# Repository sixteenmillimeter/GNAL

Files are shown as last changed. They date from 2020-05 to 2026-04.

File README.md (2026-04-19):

# GNAL

A free and open-source processing system for 16mm and Super8 film

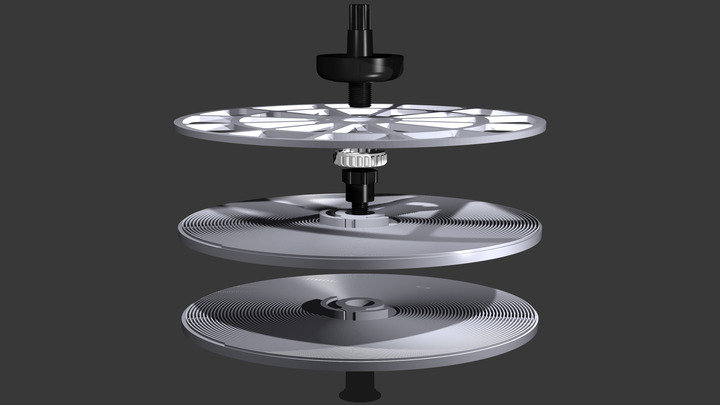
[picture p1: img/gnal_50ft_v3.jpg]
GNAL 50ft V3 all pieces


1. [What's GNAL?](#what)
2. [STL Files](#stls)
3. [Printers](#printers)
4. [Material](#material)
5. [Troubleshooting](#troubleshooting)
6. [Contact](#contact)

---

## What's GNAL? Gnal's Not A Lomo!

GNAL stands for Gnal's Not A Lomo because it isn't. 
While inspired by a certain motion picture development tank the goal of this project is to create a free, open-source, modification-friendly processing system for small format movie film with the added constraint that it be 3D printable or otherwise able to be fabricated on a small scale. 
All source code and STL files for printing will be made available in this repository.

GNAL is built using [OpenSCAD](https://www.openscad.org/): a free, open-source CAD program that uses scripts to generate objects. 
Building this project in a scripting language serves two purposes: it uses only free and open-source software to generate the GNAL processing spirals and it future-proofs the design by preserving its dimensions in human-readable text format. 
Even if OpenSCAD were to disappear tomorrow (and we sincerely hope it doesn't) it would still be possible to recreate the GNAL models in another CAD program just by reading the code and reproducing the measurements.

While the files are all free, open-source and readily available to download; actually printing them can be a challenge. 
Please read through this README for information about materials, printers and troubleshooting your prints. Check out the [development notes](docs/) if you want to modify this project. 

Happy processing!

## Other Spirals

There has been a lot of development around 3D printed processing spirals and any projects will be linked here.
If you find any, please share with the email address at the bottom of this README.

* ~~[Movie Film Spiral Developing Tank by mb_maker on Thingiverse](https://www.thingiverse.com/thing:4715086)~~
* [New 16mm developing tank on cinematography.com](https://cinematography.com/index.php?/forums/topic/83456-new-16mm-developing-tank/)

## Where's the tank?

Good question!

## Updates

Newly added to v3: reinforced spindles.
Glue or simply insert a 40mm M4 hex bolt to the top spindle and a 16mm M4 hex bolt to the bottom spindle to reinforce them and prevent breaking from overtightening or perpendicular force on the threaded areas.

----

## V3 STL Files

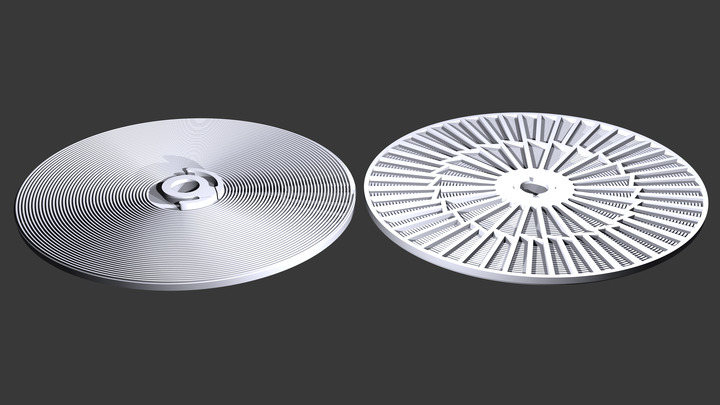
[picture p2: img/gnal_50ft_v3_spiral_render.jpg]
V3 50ft spiral top and bottom


**50ft/15m**

#### [All 50ft v3 STL files in a .zip](https://raw.githubusercontent.com/sixteenmillimeter/GNAL/main/releases/gnal_50ft_v3.zip)
#### [All 50ft v3 STL files in a .tar.gz](https://raw.githubusercontent.com/sixteenmillimeter/GNAL/main/releases/gnal_50ft_v3.tar.gz)

* [Spiral](stl/50ft_v3/gnal_50ft_spiral.stl)
* [Top](stl/50ft_v3/gnal_50ft_top.stl)
* [Top Spacer](stl/50ft_v3/gnal_50ft_spacer.stl)
* [Bottom Spiral Insert S8](stl/50ft_v3/gnal_50ft_insert_s8.stl)
* [Bottom Spiral Insert 16mm](stl/50ft_v3/gnal_50ft_insert_16.stl)
* [Bottom Spacer 16mm](stl/50ft_v3/gnal_50ft_spacer_16.stl)
* [Spindle Top](stl/50ft_v3/gnal_50ft_spindle_top.stl)
* [Spindle Top Reinforced](stl/50ft_v3.gnal_50ft_spindle_top_reinforced.stl) - Add 40mm M4 Hex Bolt
* [Spindle Bottom](stl/50ft_v3/gnal_50ft_spindle_bottom.stl)
* [Spindle Bottom Reinforced](stl/50ft_v3.gnal_50ft_spindle_bottom_reinforced.stl) - Add 16mm M4 Hex Bolt

**100ft/30m**

#### [All 100ft v3 STL files in a .zip](https://raw.githubusercontent.com/sixteenmillimeter/GNAL/main/releases/gnal_100ft_v3.zip)
#### [All 100ft v3 STL files in a .tar.gz](https://raw.githubusercontent.com/sixteenmillimeter/GNAL/main/releases/gnal_100ft_v3.tar.gz)

* [Spiral](stl/100ft_v3/gnal_100ft_spiral.stl)
* [Top](stl/100ft_v3/gnal_100ft_top.stl)
* [Top Spacer](stl/100ft_v3/gnal_100ft_spacer.stl)
* [Bottom Spiral Insert S8](stl/100ft_v3/gnal_100ft_insert_s8.stl)
* [Bottom Spiral Insert 16mm](stl/100ft_v3/gnal_100ft_insert_16.stl)
* [Bottom Spacer 16mm](stl/100ft_v3/gnal_100ft_spiral.stl)
* [Spindle Top](stl/100ft_v3/gnal_100ft_spindle_top.stl)
* [Spindle Top Reinforced](stl/50ft_v3.gnal_100ft_spindle_top_reinforced.stl) - Add 40mm M4 Hex Bolt
* [Spindle Bottom](stl/100ft_v3/gnal_100ft_spindle_bottom.stl)
* [Spindle Bottom Reinforced](stl/100ft_v3.gnal_50ft_spindle_bottom_reinforced.stl) - Add 16mm M4 Hex Bolt

## V2 STL Files

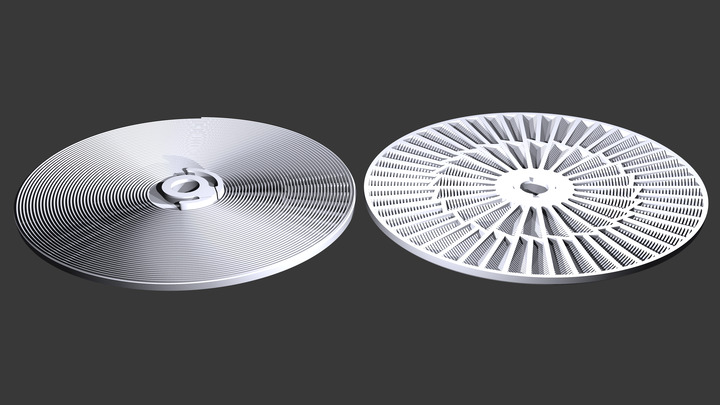
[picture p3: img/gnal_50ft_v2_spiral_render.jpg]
V2 50ft spiral top and bottom


**50ft/15m**

* [Spiral](stl/50ft_v2/gnal_50ft_spiral.stl)
* [Top](stl/50ft_v2/gnal_50ft_top.stl)
* [Top Spacer](stl/50ft_v2/gnal_50ft_spacer.stl)
* [Bottom Spiral Insert S8](stl/50ft_v2/gnal_50ft_insert_s8.stl)
* [Bottom Spiral Insert 16mm](stl/50ft_v2/gnal_50ft_insert_16.stl)
* [Bottom Spacer 16mm](stl/50ft_v2/gnal_50ft_spacer_16.stl)

**100ft/30m**

* [Spiral](stl/100ft_v2/gnal_100ft_spiral.stl)
* [Top](stl/100ft_v2/gnal_100ft_top.stl)
* [Top Spacer](stl/100ft_v2/gnal_100ft_spacer.stl)
* [Bottom Spiral Insert S8](stl/100ft_v2/gnal_100ft_spiral.stl)
* [Bottom Spiral Insert 16mm](stl/100ft_v2/gnal_100ft_insert_16.stl)
* [Bottom Spacer 16mm](stl/100ft_v2/gnal_100ft_insert_s8.stl)

## V1 STL Files

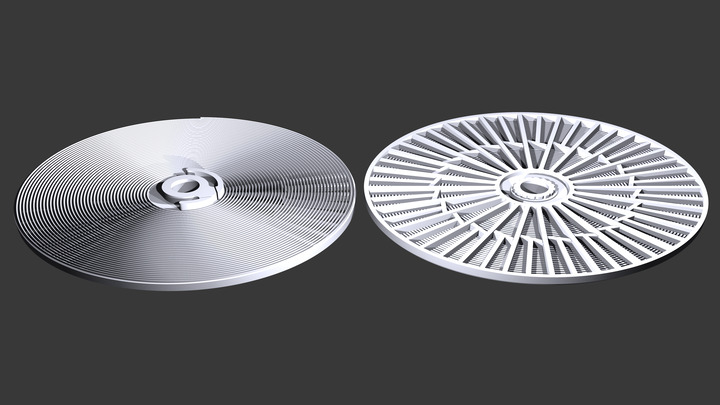
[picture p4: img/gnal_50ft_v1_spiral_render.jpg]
V1 50ft spiral top and bottom


**50ft/15m**

* [Bottom Spiral](stl/50ft_v1/gnal_50ft_spiral_bottom.stl)
* [Top Spiral](stl/50ft_v1/gnal_50ft_spiral_top.stl)
* [Top](stl/50ft_v1/gnal_50ft_top.stl)
* [Spacer](stl/50ft_v1/gnal_50ft_spacer.stl)

**100ft/30m**

* [Bottom Spiral](stl/100ft_v1/gnal_100ft_spiral_bottom.stl)
* [Top Spiral](stl/100ft_v1/gnal_100ft_spiral_top.stl)
* [Top](stl/100ft_v1/gnal_100ft_top.stl)
* [Spacer](stl/100ft_v1/gnal_100ft_spacer.stl)

-----

## Printers

The diameter of these spiral reels limit the printers that are capable of making this design. 
The 50ft/15m model is 225.71mm (8.88in) wide at the base and the 100ft/30m model is 299mm (11.77in) wide. 

**50ft/15m Capable Printers**

* [PrintrBot Metal Plus](https://www.adafruit.com/product/2302)  **Tested** **[Discontinued]**
* [LulzBot TAZ 6](https://www.lulzbot.com/store/printers/lulzbot-taz-6) Untested
* [aniwaa.com Search: Printers with print bed > 225mm x 225mm](https://www.aniwaa.com/comparison/3d-printers/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)

**100ft/30m Capable Printers**

* [Creality Ender 5 Plus](https://www.creality3d.shop/collections/3d-printer/products/creality3d-ender-5-plus-3d-printer) ***Tested***
* [aniwaa.com Search: Printers with print bed > 300mm x 300mm](https://www.aniwaa.com/comparison/3d-printers/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)

There are people printing spirals in sections on smaller printers, but that is not a *recommended* use of these files as it requires extreme precision to reconstruct the parts into a reel that will load without problems. 
Another thing to consider is the longevity of the bond made by the adhesive you choose. 
Don't let that stop you, though. A multi-part printed reel is just not a priority for *this* particular project. 
An enterprising spirit might notice the `gnal_50ft_spiral_quarter()` and `gnal_100ft_spiral_quarter()` modules in the V3 OpenSCAD scripts and begin to wonder what is possible.

-----

## Material

[PETG](https://en.wikipedia.org/wiki/Polyethylene_terephthalate#Copolymers) is currently the recommended plastic for printing the GNAL. 
Since this is a piece of darkroom processing equipment its exposure to water and photochemistry is inevitable and should be considered primarily. 
PETG (Polyethylene terephthalate glycol) is PET--which is a plastic that's typically encountered in plastic bottles and food containers--in a copolymer with glycol. 

Various manufacturers have published [safety data sheets](http://www.ilpi.com/msds/) for PETG filament. 
The only warning about reactivity I have discovered states that a condition to avoid is "strong oxidizing agents" which may include reversal bleaches that are comprised of strong acids. 
This is not a scientific evaluation and may stand to be corrected.

[ABS](https://en.wikipedia.org/wiki/Acrylonitrile_butadiene_styrene) is a viable option but has a greater tendency to warp on larger prints without proper temperature control around the print bed. 
Since this model needs to be perfectly flat across the bottom of the reel, this is not ideal and will make for a challenging print. 
ABS is a plastic commonly used in injection molding and is also generally non-reactive with photochemistry.

[PLA](https://en.wikipedia.org/wiki/Polylactic_acid) is not recommended but this doesn't mean you can't get an acceptable result with it. 
The lack of endorsement comes from mostly anecdotal experience witnessing the wear and tear caused by exposure to water on PLA prints. 
Biodegradable and porous, PLA will wear down in the weakest parts first and on this model that would be the spiral. 
If you do not need your processing equipment to last a long time, you may find it acceptable. 
PLA stands for polylactic acid and is likely the most reactive material to use with photochemistry where it is vital to maintain pH for consistent results.

-----

## Troubleshooting

Many, many issues were encountered during the development of this tool. 
Prints came out warped, failed midway during multi-day prints and had other mysterious ailments. 
I am by no means an expert but have built up months of experience trying to print these models on a variety of machines.

#### Warping

Fused filament fabrication relies on the behavior of plastics at high heat to create a physical object. 
If your prints are warping, there are a few things to look at:

1. Material
2. Temperature
3. Slicer settings

The first thing to consider when your prints are coming out warped off the print bed is whether or not your **material** is appropriate for this model. 
Check the [material](#material) section of this README for more information, but theres a chance if you are using PLA or ABS that large flat prints of this size are warping due to limitations with the material you are using. PETG has proven to warp far less in my own anecdotal experience and is the recommended material for this project.

The thermal properties of the material you're printing with are what causes warping, so check if your printer is being set to the recommended **temperatures** on both the bed and extruder for the material and printer you are using. 
Warping occurs consistently when a section of a part cools too quickly and contracts while the rest of it is still being printed. 
Mitigate this by using an enclosure on your open-frame printer or by printing in a space with low air movement but still with appropriate ventilation for the material you use.

The **slicer** you use and the **settings** in its configuration will make a lot of difference in how your print comes out. 
During the development of this project [Cura](https://ultimaker.com/software/ultimaker-cura) is the slicer used most for test prints, however you might find that different software works best with your machine. 
The settings are important to test before you commit to a complete print of the spiral part. 

Here is an example of the important settings used during development while printing with PETG.

|Setting|Value|
|---|---|
|Extruder Temperature|240<sup>o</sup> C|
|Bed Temperature|80<sup>o</sup> C|
|Generate Supports|Yes|
|Infill|20%|
|Print Speed|40 mm/s|

This is a fraction of the overall settings that Cura has, but they note some of the key features that were changed from the default profile for PETG and my printer.

-----

To read more about developing and modifying the GNAL, check out the [development notes](docs/).

-----

Had issues or success printing this? Interested in getting in contact?

# [Email me](mailto:gnal@sixteenmillimeter.com)

-----

## License

MIT License

Copyright (c) 2020 Matt McWilliams

Permission is hereby granted, free of charge, to any person obtaining a copy of this hardware, software, and associated documentation files (the "Product"), to deal in the Product without restriction, including without limitation the rights to use, copy, modify, merge, publish, distribute, sublicense, and/or sell copies of the Product, and to permit persons to whom the Product is furnished to do so, subject to the following conditions:

The above copyright notice and this permission notice shall be included in all copies or substantial portions of the Product.

THE PRODUCT IS PROVIDED "AS IS", WITHOUT WARRANTY OF ANY KIND, EXPRESS OR IMPLIED, INCLUDING BUT NOT LIMITED TO THE WARRANTIES OF MERCHANTABILITY, FITNESS FOR A PARTICULAR PURPOSE AND NONINFRINGEMENT. IN NO EVENT SHALL THE AUTHORS OR COPYRIGHT HOLDERS BE LIABLE FOR ANY CLAIM, DAMAGES OR OTHER LIABILITY, WHETHER IN AN ACTION OF CONTRACT, TORT OR OTHERWISE, ARISING FROM, OUT OF OR IN CONNECTION WITH THE PRODUCT OR THE USE OR OTHER DEALINGS IN THE PRODUCT.

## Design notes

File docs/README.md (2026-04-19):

# Development Notes

1. [Dependencies](#dependencies)
2. [Build Scripts](#scripts)
3. [Version Notes - V1](#v1)
4. [Version Notes - V2](#v2)
5. [Version Notes - V3](#v3)
6. [Benchmarks](#benchmarks)

This project can be edited with only [OpenSCAD](https://www.openscad.org/downloads.html) and the source files in the `scad/*_v1`, `scad/*_v2` or `scad/*_v3` directories which make reference to files from `scad/libraries`. 
If you wish to run the development scripts you should install the following dependencies.

With just OpenSCAD, you can use scripts such as `scad/50ft_v3/gnal_50ft.scad` and export the different modules in [OFF](https://en.wikipedia.org/wiki/OFF_(file_format)), [AMF](https://en.wikipedia.org/wiki/Additive_manufacturing_file_format), [3MF](https://en.wikipedia.org/wiki/3D_Manufacturing_Format), [DXF](https://en.wikipedia.org/wiki/AutoCAD_DXF) or SVG (drawing) format. 
The CSG models can be [imported](https://wiki.freecadweb.org/OpenSCAD_CSG) into [FreeCAD](https://www.freecadweb.org/) and DXF models should be readable by AutoCAD and [QCAD](https://www.qcad.org/en/).

-----

### Dependencies

* [Bash](https://www.gnu.org/software/bash/) - Available by default on Mac and Linux
* [OpenSCAD](https://www.openscad.org/downloads.html) + [cli](https://en.wikibooks.org/wiki/OpenSCAD_User_Manual/Using_OpenSCAD_in_a_command_line_environment) ([Mac](https://en.wikibooks.org/wiki/OpenSCAD_User_Manual/Using_OpenSCAD_in_a_command_line_environment#MacOS_notes)) ([Windows](https://en.wikibooks.org/wiki/OpenSCAD_User_Manual/Using_OpenSCAD_in_a_command_line_environment#Windows_notes))
* [ADMesh](https://github.com/admesh/admesh)
* (optional) [POV-Ray](http://www.povray.org/download/)

### Build Scripts

Running any of the build scripts scripts--`scripts/v1.sh`, `scripts/v2.sh` or `scripts/v3.sh`--will start an OpenSCAD build process of all components and will log stats about the resulting files and render times to `notes/v1.csv`,  `notes/v2.csv` or `notes/v3.csv`.

Keep in mind that V1 and V2 compile times are extremely long and all scripts will use an entire CPU core at 100% utilization while rendering. 
It's best to run these scripts in the background on a powerful machine or better yet, not at all. See the `stl` folder for pre-compiled STL files for 3D printing or the [releases page](https://github.com/sixteenmillimeter/GNAL/releases) for .zip and .tar.gz archives of all versions.

These scripts will render STL files, PNG images of the files and capture metadata about the render process while doing so.

-----

## Version Notes

### V1

Intended to be mostly compatible with existing processing spirals with some caveats. 
A spacer that is typically threaded has been replaced by a friction fit part so they are not interchangeable. 
This version is designed to fit in existing tanks and use the same spindle screws.

In the process of building this first version several approaches were evaluated to generate the spiral shape. 
The first is what's best described as a brute force approach laying out an excessive amount of rectangular facets and unioning them together in such a way that the result would be a single continuous spiral. 
This took hours to days to render depending on the machine used.

Besides the exhausting render times this approach bugged me for one reason: all facets of the spiral were the same size, meaning that the small diameter inner parts of the spiral were packing in millions of unnecessary polygons to allow for the large diameter parts of the spiral to be smooth. 
This didn't sit well with me. 
How many CPU hours are being burned by adding detail to a place that doesn't matter? 
Answer: a lot.

Finally, an external library called [`path_extrude.scad`](https://github.com/gringer/bioinfscripts/blob/master/path_extrude.scad) by [@gringer](https://github.com/gringer) was brought in to handle the complicated spiral extrusion step. 
A simple function that plots a spiral in Cartesian coordinates is used to draw the path and a 2D triangle is extruded along it by the library. 
This allowed for the path to be drawn at a consistent "resolution" throughout the entire spiral, so the facets of the outermost and innermost parts were the same or extremely similar.

Here is that function reduced to a single line in order to generate an array of coordinates.

```
spiralPath = [ for(t = [0 : $fn + 1]) [((d / 2) + (t * increment)) * cos(t * angle_i), ((d / 2) + (t * increment)) * sin(t * angle_i), 0] ];
```

The experimentation in this version predate this particular git repo and so will not be found in the git history, but you can find the vestigial functions in the `spiral` directory used for benchmarking different approaches.

#### Beware

This version of the spiral must be printed with supports. 
The spirals themselves are suspended over voids and this particular feature is addressed in the later versions. 

#### Rendering

Rendered using OpenSCAD version 2019.05 on a 2.2 GHz Core i7 (I7-4770HQ) chip running macOS 10.14.

| Model | Size (bytes) | Facets | Volume (mm<sup>3</sup>) | Render Time (sec) |
|---|---|---|---|---|
|gnal_50ft_spacer.stl|991452|5736|2888.155029|68|
|gnal_50ft_top.stl|2132181|12624|57936.746094|233|
| **gnal_50ft_spiral_top.stl** |36509561|214404|120299.773438| **12249** |
| **gnal_50ft_spiral_bottom.stl** |36606204|214970|121519.937500| **13698** |
|gnal_100ft_spacer.stl|991452|5736|2888.149658|74|
|gnal_100ft_top.stl|3302563|19552|102590.546875|477|
|gnal_100ft_spiral_top.stl|92423369|542836|223602.078125|89137|
|gnal_100ft_spiral_bottom.stl|N/A|N/A|N/A|N/A|

-----

### V2

This version aims to improve printability over the V1 model and reducing render time of the spiral. 
The biggest change to the physical structure of the design is the removal of overhangs from beneath the spiral film guide.

When printing a model with [FFF printing](https://en.wikipedia.org/wiki/Fused_filament_fabrication), any piece that overhangs empty space (usually) needs to be supported by a temporary removable structure beneath it otherwise you risk the piece drooping. 
In the case of V1 model, the spiral was completely suspended by the spokes of the reel with large gaps of empty space. 
This means there were 90 degree overhangs under the most critical part of this model; the grooves for holding the film in position. 
Printing and removing support structures from beneath the fragile spiral made post-production dangerous for the piece and time consuming.

The solution to this was to extend the spiral to the bottom of the reel and remove triangular sections from them to allow for a lighter print and better chemistry movement. 
Most printers should be able to print these structures without any support material or any resulting deformations in the model.

One other change in this version is that it reduces the spiral models to a single one to be duplicated, rather than two distinct top and a bottom pieces that differ in only minor ways. 
This decision was motivated by an interest in making this design better (cheaper) for injection molding.

A secondary benefit of reducing the spiral to a single model was to immediately cut render times for the entire project nearly in half before any other optimizations were made. 
The first meaningful code optimization toward this goal was provided by a helpful comment made on a long-forgotten design shared on a 3D printing forum. 

[@sousvide59](https://www.thingiverse.com/sousvide59/designs) (Les Smith) writes 

> It may be more efficient to approximate the spiral as a series of arc segments, like this <[Github gist](https://gist.github.com/sixteenmillimeter/839c16d39d26d04154f52b3f3ee6ee78)>.

Les was right. 
This reduced the several hours render time to 1-2 hours, which worked for this version. Ideally this will be improved further in future versions. 
Beyond some explorations into OpenSCAD hacks (rendering each complete rotation of the spiral and stitching all resulting STLs) the next version will incorporate other languages and platforms to find the fastest render time for a GNAL spiral. 
All previous approaches are being compiled into a suite of tests to benchmark render times.

#### Rendering

Rendered using OpenSCAD version 2020.01.17 on a 3.2 GHz Core i5 (I5-4460) chip running Ubuntu 18.04.

| Model | Size (bytes) | Facets | Volume (mm<sup>3</sup>) | Render Time (sec) |
|---|---|---|---|---|
|gnal_50ft_spacer.stl|991452|5736|2888.150879|22|
|gnal_50ft_top.stl|2132181|12624|57937.210938|73|
| **gnal_50ft_spiral.stl** |34628449|193450|178181.250000| **2341** |
|gnal_50ft_insert_s8.stl|5228272|27230|3493.560303|97|
|gnal_50ft_insert_16.stl|7922994|41426|4664.952637|155|
|gnal_50ft_spacer_16.stl|561267|3272|4015.912109|19|
|gnal_100ft_spacer.stl|991452|5736|2888.152100|23|
|gnal_100ft_top.stl|3302563|19552|102590.812500|118|
| **gnal_100ft_spiral.stl** |59279238|330000|345431.531250| **4542** |
|gnal_100ft_insert_s8.stl|5228272|27230|3493.559326|99|
|gnal_100ft_insert_16.stl|7922994|41426|4664.937500|160|
|gnal_100ft_spacer_16.stl|535264|3112|3964.118164|17|

-----

### V3

The goals of V3 are to **greatly** optimize the spiral generation code for speed and to restore the feature of the V1 spiral which maintains a consistent size of individual facets throughout the spiral even as the diameter changes. 
This will be considered a stable release candidate for publishing the project.

Since the benchmarking process ([see below](#benchmarks)) was developed between V2 and V3, render times are optimized in this iteration of the project. 
The success of the [`spiral_3.scad`](../scad/spiral/spiral_3.scad) approach stood out from the rest as fastest, so it was reworked into what exists in V3.

The spiral itself is plotted in 2D with a relatively simple formula that is expressed in this OpenSCAD script through a number of in-line helper functions. 
It draws the position of various points along the spiral path and then uses the `path_extrude.scad` library to extrude a shape along those coordinates. 
This proves to be fast and efficient while not sacrificing any detail in the geometry.

Prior to release a serious flaw was found while printing the V3 design. 
The attempt to remove the need for supports in V2, actually printing the spiral was creating curious side effects during fabrication. 
Not having material in the voids below the spiral, it seems, allowed air to cool the part and would consistently cause prints to fail when it reached the actual spiral at the top of the reel. 
Since this is the most important element of the reel, the triangles have been removed and the design is more similar to V1. 
Testing continues on this version.

In a compromise to make the process of removing the support material less dangerous to the detail on the top, the spiral itself extends lower than V1 into the space between the spokes of the reel. 
The spiral is also made thicker and is a multiple of my nozzle diameter (0.4mm). 
This uses slightly more material but is less fragile than V1 and test prints proved that the supports were less difficult to remove than in the earliest model.

This version will also contain a 4x reel stacking feature so that all models can be stacked with 4 spiral reels and a top piece. 
That will give 200ft capacity to the 50ft model and 400ft capacity to the 100ft model. 
A stretch goal for this version is to make a 35mm spacer and spindle set so that movie film in the format can be processed in 100ft lengths.

#### Beware

This version *also* requires the use of support material while printing.

#### Rendering

Rendered using OpenSCAD version 2020.08.18 on a 2.2 GHz Core i7 (I7-4770HQ) chip running macOS 10.14.

| Model | Size (bytes) | Facets | Volume (mm<sup>3</sup>) | Render Time (sec) |
|---|---|---|---|---|
|gnal_50ft_spindle_bottom.stl|3760384|75206|4134.077637|1291|
|gnal_50ft_spindle_top.stl|6915384|138306|22229.814453|1128|
|gnal_50ft_spacer.stl|286884|5736|2888.150635|62|
|gnal_50ft_top.stl|1104884|22096|57933.800781|585|
| **gnal_50ft_spiral.stl** |9500384|190006|171712.140625| **1111** |
|gnal_50ft_insert_s8.stl|1361584|27230|3493.544922|276|
|gnal_50ft_insert_16.stl|2071384|41426|4665.019531|439|
|gnal_50ft_spacer_16.stl|602084|12040|4019.470703|281|
|gnal_100ft_spindle_bottom.stl|3760384|75206|4134.064941|1275|
|gnal_100ft_spindle_top.stl|6979184|139582|22229.773438|1139|
|gnal_100ft_spacer.stl|286884|5736|2888.143555|63|
|gnal_100ft_top.stl|1620084|32400|102557.437500|998|
| **gnal_100ft_spiral.stl** |18364384|367286|326573.812500| **3746** |
|gnal_100ft_insert_s8.stl|1361584|27230|3493.548340|272|
|gnal_100ft_insert_16.stl|2071384|41426|4664.790527|450|
|gnal_100ft_spacer_16.stl|755684|15112|4019.479248|368|

## Benchmarks

In the process of publishing this repository I started questioning claims I was making in this README. 
Throughout the development of this processing reel I've been plagued by long render times. 
As a sanity check, I went through my personal development history on this project and produced 6 distinct spiral generation scripts that I ran through a series of tests to benchmark the render performance, total volume generated and number of facets produced. 
Render time was the primary metric that concerned me, but I considered the others important in comparing these different approaches. 

This work led to the creation of the approach in `spiral_7.scad` and was ultimately used in V3.

An example of a single test pulled from the `notes/benchmark.csv` results. 
These example results are rendered using OpenSCAD 2020.05.23 on a 2.3 GHz Xeon Gold 6140 chip running Ubuntu 18.04.

|Spiral Test|Diameter (mm)|Rotations| [$fn](https://en.wikibooks.org/wiki/OpenSCAD_User_Manual/Other_Language_Features#$fa,_$fs_and_$fn) |Size (bytes)|Facets|Volume (mm<sup>3</sup>)|Time (sec)|
|---|---|---|---|---|---|---|---|
|[spiral_1.scad](../scad/spiral/spiral_1.scad)|47|10|100|7409653|41064|5391.819336|209|
|[spiral_2.scad](../scad/spiral/spiral_2.scad)|47|10|100|15349620|86646|3639.441162|855|
|[spiral_3.scad](../scad/spiral/spiral_3.scad)|47|10|100|1336635|8004|3589.485596|0|
|[spiral_4.scad](../scad/spiral/spiral_4.scad)|47|10|100|1607691|9624|3830.134521|23|
|[spiral_5.scad](../scad/spiral/spiral_5.scad)|47|10|100|4711486|28188|3602.101562|8|
|[spiral_6.scad](../scad/spiral/spiral_6.scad)|47|10|100|4265376|25396|14337.455078|120|
|[spiral_7.scad](../scad/spiral/spiral_7.scad)|47|10|100|990006|5924|3581.499756|0|

As you can see, the different approaches lead to wildly different render times for the same test. 
If you look at the complete results you will see many tests did not even finish due to exhausting memory on the machine or the process being killed by the cloud host (using too much CPU for too long, most likely). 
In the case of `spiral_3.scad` and `spiral_7.scad` measuring "0" seconds, this just means that the process finished rendering in less than 1 second.

In the `scad/spiral` directory you will find each individual script in a `scad/spiral/spiral_#.scad` file. 
The `scripts/benchmark.sh` script will render spirals at various resolutions and rotation counts and record the results in `notes/benchmark.csv`.

Insights gleaned from these benchmarks was incorporated into the latest versions of design. 
Consider this comparison of just the 50ft spirals (top spiral from V1).

| # | Model | Size (bytes) | Facets | Volume (mm<sup>3</sup>) | Render Time (sec) |
|---|---|---|---|---|---|
| V1 | gnal_50ft_spiral_top.stl |36509561 | 214404 | 120299.773438 | 12249 |
| V2 | gnal_50ft_spiral.stl |34628449 | 193450 | 178181.250000 |  2341 |
| V3 | gnal_50ft_spiral.stl | 9500384 | 190006 | 171712.140625 |  1111 |

Render times have gone down dramatically between V1 and V2.
Times halved again between V2 and V3.
The volume has stayed consistent with major changes in geometry (between V1 and V2).
The file size of the V3 spiral has reduced to about 30% of the V1 and V2 spirals and the facet count remains roughly the same throughout (which was a surprise).

Faster render times mean more iteration and less time between tests.
The next part of the process to examine is slicing which has primarily been done with Cura, but other engines will be looked at for their speed, efficiency and print quality.

## V3 Updates

### Reinforced Spindles

The first in a list of intended updates to the V3 model is reinforcing the spindles.
This is acheived by adding voids for M4 bolts in the spindles with the intention of preventing them from snapping due to overtightening or perpendicular force on the threaded parts.
The bolts should be friction fit or added with a small amount of glue to adhere them inside the spindles.

* 1x 40mm M4 Hex Bolt *(Accepts 30-50mm bolts if needed)*
* 1x 16mm M4 Hex Bolt

### Manifold Backend

Another upgrade in the build script is the use of the [Manifold](https://manifoldcad.org/docs/html/) backend.
This drops the CPU render time dramatically, even after the spiral modifications in V3.

OpenSCAD has improved performance in the core backend since starting this project, but rendering using `--backend=manifold` drops even the most complex solid geometry calculations to times needed for fast design iterations.

### Canonical Renders

The next improvement was to introduce [c14n_stl.py](https://github.com/nophead/NopSCADlib/blob/master/scripts/c14n_stl.py) from [NopSCADlib](https://github.com/nophead/NopSCADlib) to sort compiled STLs consistently between renders.
Doing this *should* mean that different machines will produce identical STLs before they're converted to binary and prevent excessive diffs when small changes are made.
Previously this was left out to reduce the Python dependency but it is common enough as a default on many systems to mean that adding a library-free Python script is not a concern.

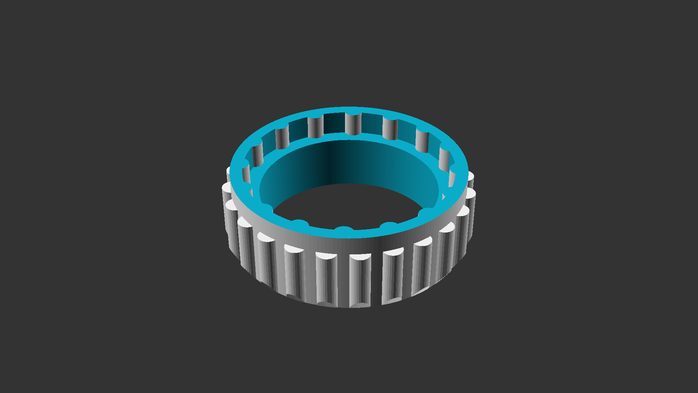
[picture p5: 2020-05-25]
img/gnal_50ft_v3_spacer.png

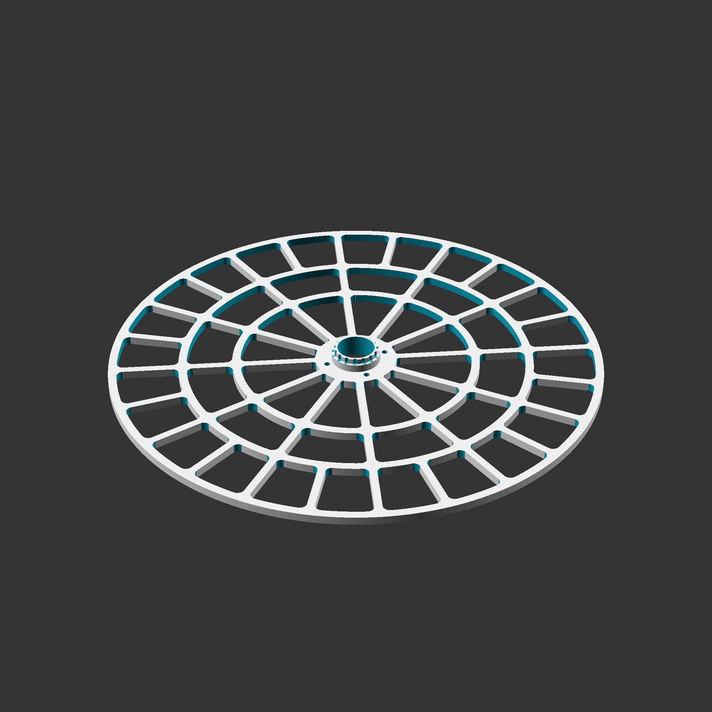
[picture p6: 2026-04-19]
img/gnal_100ft_v3_top.png

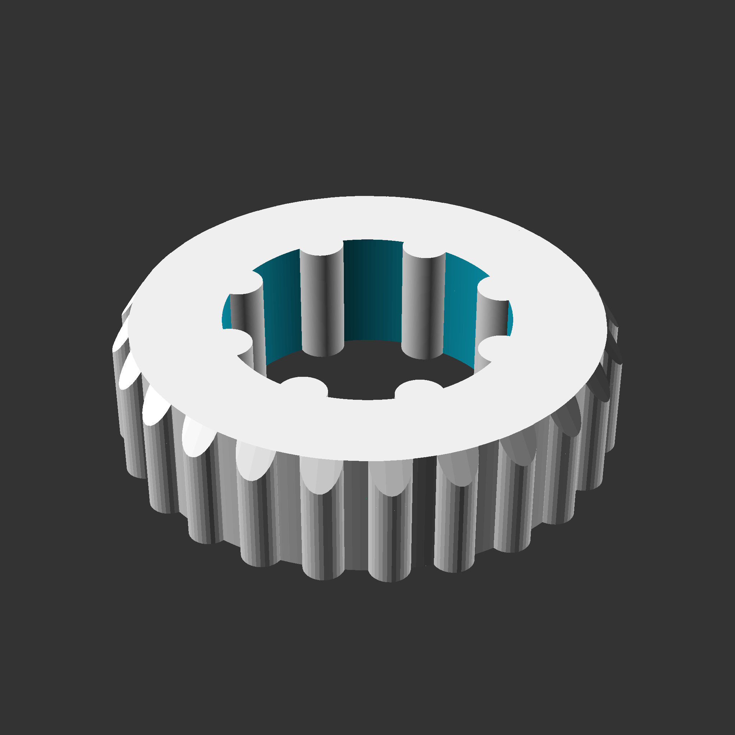
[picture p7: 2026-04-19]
img/gnal_50ft_v3_spacer_16.png

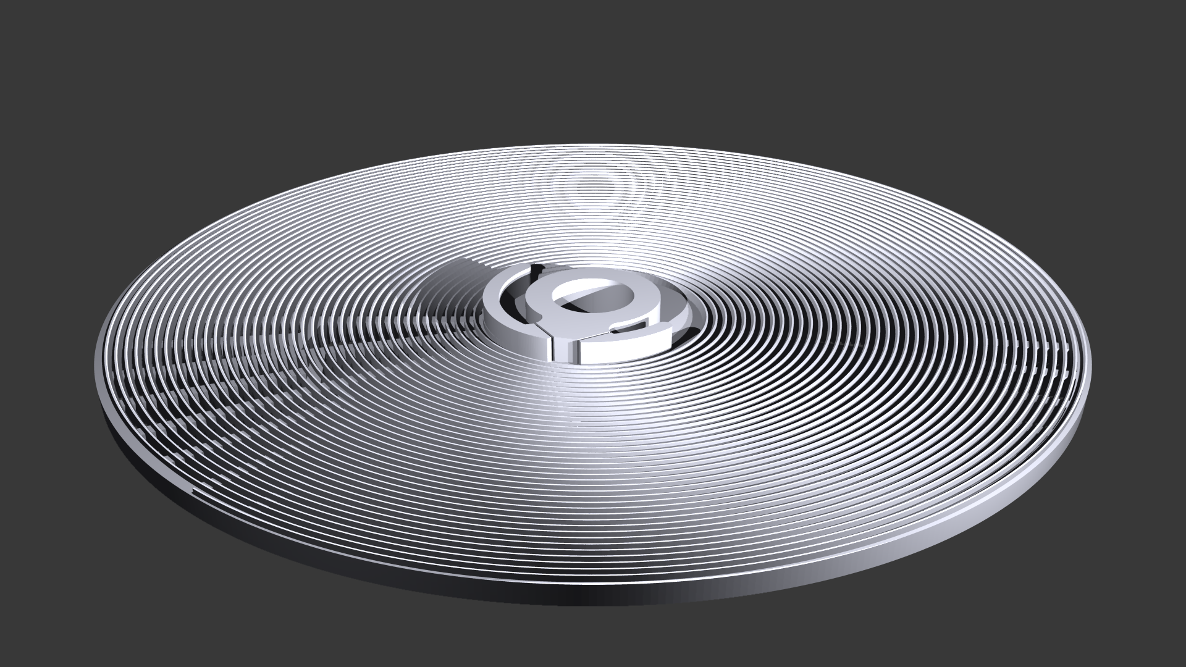
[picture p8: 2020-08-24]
img/gnal_50ft_v3_spiral-povray.png

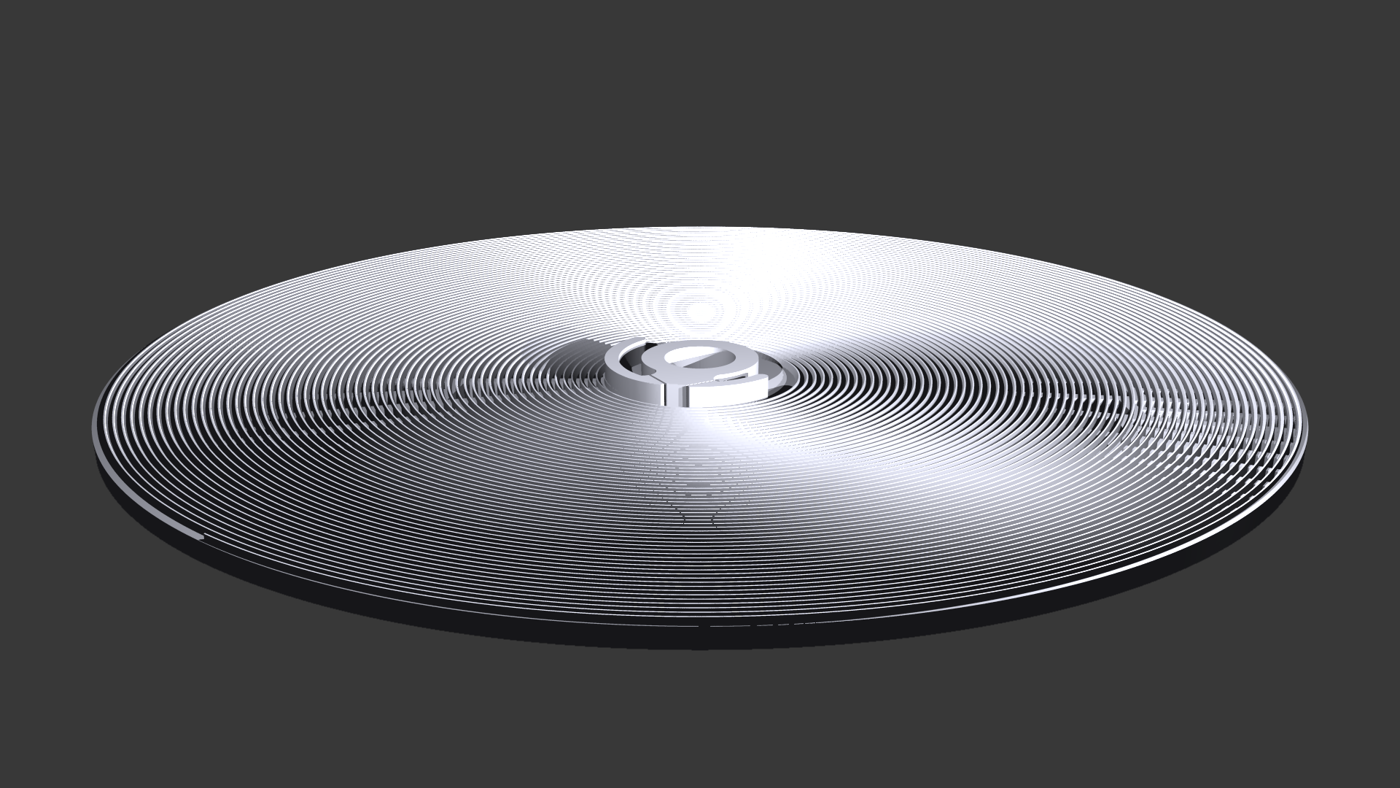
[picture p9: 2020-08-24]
img/gnal_100ft_v3_spiral-povray.png

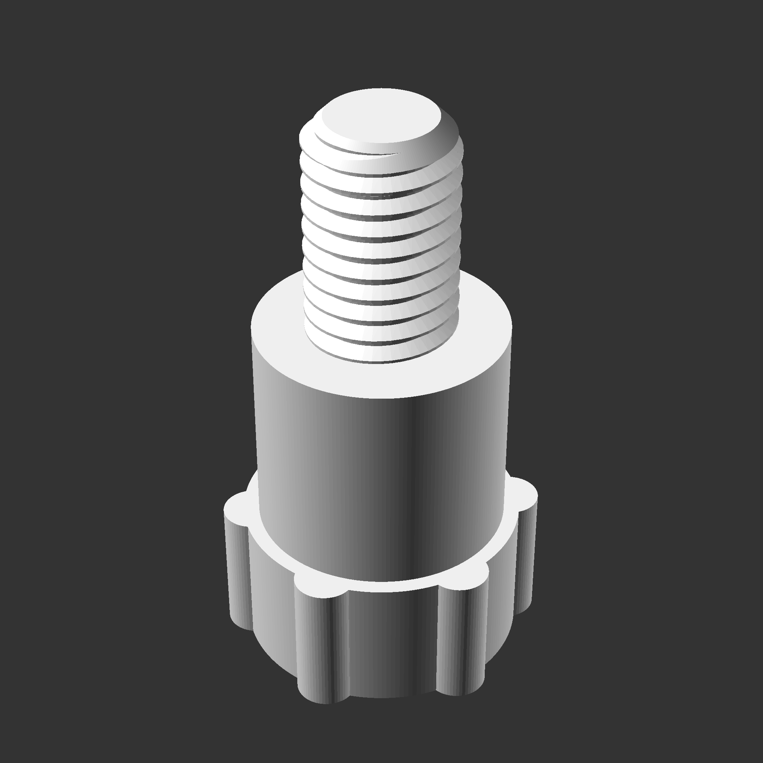
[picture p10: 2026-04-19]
img/gnal_50ft_v3_spindle_bottom.png

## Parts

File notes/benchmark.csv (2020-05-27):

version | cpu | date | source | diameter | rotations | fn | size | facets | volume | time
2020.05.23 | Intel(R) Xeon(R) Gold 6140 CPU @ 2.30GHz | 1590257297 | spiral_1.scad | 47 | 1 | 100 | 600972 | 3336 | 381.905853 | 11
2020.05.23 | Intel(R) Xeon(R) Gold 6140 CPU @ 2.30GHz | 1590257297 | spiral_1.scad | 225 | 1 | 100 | 803707 | 4492 | 1801.689819 | 13
2020.05.23 | Intel(R) Xeon(R) Gold 6140 CPU @ 2.30GHz | 1590257297 | spiral_1.scad | 300 | 1 | 100 | 803720 | 4514 | 2399.897217 | 13
2020.05.23 | Intel(R) Xeon(R) Gold 6140 CPU @ 2.30GHz | 1590257297 | spiral_1.scad | 47 | 2 | 100 | 1208982 | 6706 | 795.789734 | 31
2020.05.23 | Intel(R) Xeon(R) Gold 6140 CPU @ 2.30GHz | 1590257297 | spiral_1.scad | 225 | 2 | 100 | 1606362 | 8980 | 3621.282471 | 35
2020.05.23 | Intel(R) Xeon(R) Gold 6140 CPU @ 2.30GHz | 1590257297 | spiral_1.scad | 300 | 2 | 100 | 1647731 | 9242 | 4811.801758 | 35
2020.05.23 | Intel(R) Xeon(R) Gold 6140 CPU @ 2.30GHz | 1590257297 | spiral_1.scad | 47 | 5 | 100 | 3299087 | 18290 | 2251.599365 | 90
2020.05.23 | Intel(R) Xeon(R) Gold 6140 CPU @ 2.30GHz | 1590257297 | spiral_1.scad | 225 | 5 | 100 | 4104104 | 22926 | 9294.243164 | 104
2020.05.23 | Intel(R) Xeon(R) Gold 6140 CPU @ 2.30GHz | 1590257297 | spiral_1.scad | 300 | 5 | 100 | 4080931 | 22910 | 12261.650391 | 106
2020.05.23 | Intel(R) Xeon(R) Gold 6140 CPU @ 2.30GHz | 1590257297 | spiral_1.scad | 47 | 10 | 100 | 7409653 | 41064 | 5391.819336 | 209
2020.05.23 | Intel(R) Xeon(R) Gold 6140 CPU @ 2.30GHz | 1590257297 | spiral_1.scad | 225 | 10 | 100 | 8398250 | 46902 | 19462.734375 | 244
2020.05.23 | Intel(R) Xeon(R) Gold 6140 CPU @ 2.30GHz | 1590257297 | spiral_1.scad | 300 | 10 | 100 | 7985068 | 44890 | 25391.878906 | 238
2020.05.23 | Intel(R) Xeon(R) Gold 6140 CPU @ 2.30GHz | 1590257297 | spiral_1.scad | 47 | 20 | 100 | 15661917 | 86774 | 14349.499023 | 583
2020.05.23 | Intel(R) Xeon(R) Gold 6140 CPU @ 2.30GHz | 1590257297 | spiral_1.scad | 225 | 20 | 100 | 16761859 | 93756 | 42476.390625 | 653
2020.05.23 | Intel(R) Xeon(R) Gold 6140 CPU @ 2.30GHz | 1590257297 | spiral_1.scad | 300 | 20 | 100 | 15509322 | 87376 | 54329.035156 | 616
2020.05.23 | Intel(R) Xeon(R) Gold 6140 CPU @ 2.30GHz | 1590257297 | spiral_2.scad | 47 | 1 | 100 | 789816 | 4450 | 263.114624 | 14
2020.05.23 | Intel(R) Xeon(R) Gold 6140 CPU @ 2.30GHz | 1590257297 | spiral_2.scad | 225 | 1 | 100 | 11168654 | 63830 | 1216.353271 | 1128
2020.05.23 | Intel(R) Xeon(R) Gold 6140 CPU @ 2.30GHz | 1590257297 | spiral_2.scad | 300 | 1 | 100 | 16605036 | 95758 | 1616.316895 | 4695
2020.05.23 | Intel(R) Xeon(R) Gold 6140 CPU @ 2.30GHz | 1590257297 | spiral_2.scad | 47 | 2 | 100 | 1688799 | 9526 | 549.006348 | 38
2020.05.23 | Intel(R) Xeon(R) Gold 6140 CPU @ 2.30GHz | 1590267611 | spiral_1.scad | 47 | 40 | 100 |  |  |  | 1113
2020.05.23 | Intel(R) Xeon(R) Gold 6140 CPU @ 2.30GHz | 1590267611 | spiral_1.scad | 47 | 60 | 100 |  |  |  | 385
2020.05.23 | Intel(R) Xeon(R) Gold 6140 CPU @ 2.30GHz | 1590267611 | spiral_2.scad | 47 | 1 | 100 | 789816 | 4450 | 263.114624 | 14
2020.05.23 | Intel(R) Xeon(R) Gold 6140 CPU @ 2.30GHz | 1590267611 | spiral_2.scad | 225 | 1 | 100 | 11168654 | 63830 | 1216.353516 | 1122
2020.05.23 | Intel(R) Xeon(R) Gold 6140 CPU @ 2.30GHz | 1590267611 | spiral_2.scad | 300 | 1 | 100 | 16605036 | 95758 | 1616.317627 | 4698
2020.05.23 | Intel(R) Xeon(R) Gold 6140 CPU @ 2.30GHz | 1590267611 | spiral_2.scad | 47 | 2 | 100 | 1688799 | 9526 | 549.006470 | 37
2020.05.23 | Intel(R) Xeon(R) Gold 6140 CPU @ 2.30GHz | 1590267611 | spiral_2.scad | 225 | 2 | 100 |  |  |  | 3571
2020.05.23 | Intel(R) Xeon(R) Gold 6140 CPU @ 2.30GHz | 1590267611 | spiral_2.scad | 300 | 2 | 100 |  |  |  | 4731
2020.05.23 | Intel(R) Xeon(R) Gold 6140 CPU @ 2.30GHz | 1590267611 | spiral_2.scad | 47 | 5 | 100 | 5346893 | 30172 | 1540.823730 | 168
2020.05.23 | Intel(R) Xeon(R) Gold 6140 CPU @ 2.30GHz | 1590267611 | spiral_2.scad | 225 | 5 | 100 |  |  |  | 6989
2020.05.23 | Intel(R) Xeon(R) Gold 6140 CPU @ 2.30GHz | 1590267611 | spiral_2.scad | 300 | 5 | 100 |  |  |  | 4467
2020.05.23 | Intel(R) Xeon(R) Gold 6140 CPU @ 2.30GHz | 1590267611 | spiral_2.scad | 47 | 10 | 100 | 15349620 | 86646 | 3639.441162 | 855
2020.05.23 | Intel(R) Xeon(R) Gold 6140 CPU @ 2.30GHz | 1590267611 | spiral_2.scad | 225 | 10 | 100 |  |  |  | 4759
2020.05.23 | Intel(R) Xeon(R) Gold 6140 CPU @ 2.30GHz | 1590267611 | spiral_2.scad | 300 | 10 | 100 |  |  |  | 2662
2020.05.23 | Intel(R) Xeon(R) Gold 6140 CPU @ 2.30GHz | 1590267611 | spiral_2.scad | 47 | 20 | 100 |  |  |  | 1659
2020.05.23 | Intel(R) Xeon(R) Gold 6140 CPU @ 2.30GHz | 1590267611 | spiral_2.scad | 225 | 20 | 100 |  |  |  | 2759
2020.05.23 | Intel(R) Xeon(R) Gold 6140 CPU @ 2.30GHz | 1590267611 | spiral_2.scad | 300 | 20 | 100 |  |  |  | 880
2020.05.23 | Intel(R) Xeon(R) Gold 6140 CPU @ 2.30GHz | 1590267611 | spiral_2.scad | 47 | 40 | 100 |  |  |  | 1578
2020.05.23 | Intel(R) Xeon(R) Gold 6140 CPU @ 2.30GHz | 1590267611 | spiral_2.scad | 47 | 60 | 100 |  |  |  | 1298
2020.05.23 | Intel(R) Xeon(R) Gold 6140 CPU @ 2.30GHz | 1590267611 | spiral_3.scad | 47 | 1 | 100 | 134313 | 804 | 262.170135 | 0
2020.05.23 | Intel(R) Xeon(R) Gold 6140 CPU @ 2.30GHz | 1590267611 | spiral_3.scad | 225 | 1 | 100 | 134269 | 804 | 1183.955444 | 0
2020.05.23 | Intel(R) Xeon(R) Gold 6140 CPU @ 2.30GHz | 1590267611 | spiral_3.scad | 300 | 1 | 100 | 134365 | 804 | 1572.317627 | 0
2020.05.23 | Intel(R) Xeon(R) Gold 6140 CPU @ 2.30GHz | 1590267611 | spiral_3.scad | 47 | 2 | 100 | 267846 | 1604 | 545.908936 | 0
2020.05.23 | Intel(R) Xeon(R) Gold 6140 CPU @ 2.30GHz | 1590267611 | spiral_3.scad | 225 | 2 | 100 | 267837 | 1604 | 2389.486816 | 1
2020.05.23 | Intel(R) Xeon(R) Gold 6140 CPU @ 2.30GHz | 1590267611 | spiral_3.scad | 300 | 2 | 100 | 268195 | 1604 | 3166.378174 | 0
2020.05.23 | Intel(R) Xeon(R) Gold 6140 CPU @ 2.30GHz | 1590267611 | spiral_3.scad | 47 | 5 | 100 | 668359 | 4004 | 1526.071045 | 0
2020.05.23 | Intel(R) Xeon(R) Gold 6140 CPU @ 2.30GHz | 1590267611 | spiral_3.scad | 225 | 5 | 100 | 668390 | 4004 | 6134.965332 | 0
2020.05.23 | Intel(R) Xeon(R) Gold 6140 CPU @ 2.30GHz | 1590267611 | spiral_3.scad | 300 | 5 | 100 | 669164 | 4004 | 8077.240723 | 1
2020.05.23 | Intel(R) Xeon(R) Gold 6140 CPU @ 2.30GHz | 1590267611 | spiral_3.scad | 47 | 10 | 100 | 1336635 | 8004 | 3589.485596 | 0
2020.05.23 | Intel(R) Xeon(R) Gold 6140 CPU @ 2.30GHz | 1590267611 | spiral_3.scad | 225 | 10 | 100 | 1336668 | 8004 | 12807.394531 | 1
2020.05.23 | Intel(R) Xeon(R) Gold 6140 CPU @ 2.30GHz | 1590267611 | spiral_3.scad | 300 | 10 | 100 | 1337659 | 8004 | 16691.759766 | 1
2020.05.23 | Intel(R) Xeon(R) Gold 6140 CPU @ 2.30GHz | 1590267611 | spiral_3.scad | 47 | 20 | 100 | 2673096 | 16004 | 9328.120117 | 2
2020.05.23 | Intel(R) Xeon(R) Gold 6140 CPU @ 2.30GHz | 1590267611 | spiral_3.scad | 225 | 20 | 100 | 2673089 | 16004 | 27763.302734 | 2
2020.05.23 | Intel(R) Xeon(R) Gold 6140 CPU @ 2.30GHz | 1590267611 | spiral_3.scad | 300 | 20 | 100 | 2674182 | 16004 | 35531.792969 | 2
2020.05.23 | Intel(R) Xeon(R) Gold 6140 CPU @ 2.30GHz | 1590267611 | spiral_3.scad | 47 | 40 | 100 | 5346008 | 32004 | 27252.826172 | 9
2020.05.23 | Intel(R) Xeon(R) Gold 6140 CPU @ 2.30GHz | 1590267611 | spiral_3.scad | 47 | 60 | 100 | 8019095 | 48004 | 53773.640625 | 22
2020.05.23 | Intel(R) Xeon(R) Gold 6140 CPU @ 2.30GHz | 1590267611 | spiral_4.scad | 47 | 1 | 100 | 79570 | 476 | 283.918793 | 0
2020.05.23 | Intel(R) Xeon(R) Gold 6140 CPU @ 2.30GHz | 1590267611 | spiral_4.scad | 225 | 1 | 100 | 1774211 | 10620 | 1264.982422 | 1
2020.05.23 | Intel(R) Xeon(R) Gold 6140 CPU @ 2.30GHz | 1590267611 | spiral_4.scad | 300 | 1 | 100 | 3152086 | 18868 | 1679.437256 | 3
2020.05.23 | Intel(R) Xeon(R) Gold 6140 CPU @ 2.30GHz | 1590267611 | spiral_4.scad | 47 | 2 | 100 | 175601 | 1052 | 585.684998 | 1
2020.05.23 | Intel(R) Xeon(R) Gold 6140 CPU @ 2.30GHz | 1590267611 | spiral_4.scad | 225 | 2 | 100 | 3611465 | 21636 | 2551.925049 | 53
2020.05.23 | Intel(R) Xeon(R) Gold 6140 CPU @ 2.30GHz | 1590267611 | spiral_4.scad | 300 | 2 | 100 | 6386412 | 38260 | 3381.085693 | 162
2020.05.23 | Intel(R) Xeon(R) Gold 6140 CPU @ 2.30GHz | 1590267611 | spiral_4.scad | 47 | 5 | 100 | 561609 | 3362 | 1629.687500 | 4
2020.05.23 | Intel(R) Xeon(R) Gold 6140 CPU @ 2.30GHz | 1590267611 | spiral_4.scad | 225 | 5 | 100 | 9536133 | 57130 | 6550.488281 | 639
2020.05.23 | Intel(R) Xeon(R) Gold 6140 CPU @ 2.30GHz | 1590267611 | spiral_4.scad | 300 | 5 | 100 | 16636338 | 99668 | 8623.676758 | 2285
2020.05.23 | Intel(R) Xeon(R) Gold 6140 CPU @ 2.30GHz | 1590267611 | spiral_4.scad | 47 | 10 | 100 | 1607691 | 9624 | 3830.134521 | 23
2020.05.23 | Intel(R) Xeon(R) Gold 6140 CPU @ 2.30GHz | 1590267611 | spiral_4.scad | 225 | 10 | 100 | 20840399 | 124850 | 13673.706055 | 4314
2020.05.23 | Intel(R) Xeon(R) Gold 6140 CPU @ 2.30GHz | 1590267611 | spiral_4.scad | 300 | 10 | 100 |  |  |  | 45944
2020.05.23 | Intel(R) Xeon(R) Gold 6140 CPU @ 2.30GHz | 1590267611 | spiral_4.scad | 47 | 20 | 100 | 5726140 | 34290 | 9954.101562 | 344
2020.05.23 | Intel(R) Xeon(R) Gold 6140 CPU @ 2.30GHz | 1590267611 | spiral_4.scad | 225 | 20 | 100 |  |  |  | 181
2020.05.23 | Intel(R) Xeon(R) Gold 6140 CPU @ 2.30GHz | 1590267611 | spiral_4.scad | 300 | 20 | 100 |  |  |  | 235
2020.05.23 | Intel(R) Xeon(R) Gold 6140 CPU @ 2.30GHz | 1590267611 | spiral_4.scad | 47 | 40 | 100 | 26318101 | 157622 | 29088.138672 | 7778
2020.05.23 | Intel(R) Xeon(R) Gold 6140 CPU @ 2.30GHz | 1590267611 | spiral_4.scad | 47 | 60 | 100 |  |  |  | 124
2020.05.23 | Intel(R) Xeon(R) Gold 6140 CPU @ 2.30GHz | 1590267611 | spiral_5.scad | 47 | 1 | 100 | 232086 | 1388 | 260.903351 | 1
2020.05.23 | Intel(R) Xeon(R) Gold 6140 CPU @ 2.30GHz | 1590267611 | spiral_5.scad | 225 | 1 | 100 | 5315474 | 31812 | 1184.967529 | 10
2020.05.23 | Intel(R) Xeon(R) Gold 6140 CPU @ 2.30GHz | 1590267611 | spiral_5.scad | 300 | 1 | 100 | 9448007 | 56548 | 1573.830444 | 29
2020.05.23 | Intel(R) Xeon(R) Gold 6140 CPU @ 2.30GHz | 1590267611 | spiral_5.scad | 47 | 2 | 100 | 507766 | 3036 | 545.301697 | 0
2020.05.23 | Intel(R) Xeon(R) Gold 6140 CPU @ 2.30GHz | 1590267611 | spiral_5.scad | 225 | 2 | 100 | 10831693 | 64820 | 2391.967285 | 39
2020.05.23 | Intel(R) Xeon(R) Gold 6140 CPU @ 2.30GHz | 1590267611 | spiral_5.scad | 300 | 2 | 100 | 19164101 | 114692 | 3169.562988 | 125
2020.05.23 | Intel(R) Xeon(R) Gold 6140 CPU @ 2.30GHz | 1590267611 | spiral_5.scad | 47 | 5 | 100 | 1630973 | 9756 | 1528.758545 | 1
2020.05.23 | Intel(R) Xeon(R) Gold 6140 CPU @ 2.30GHz | 1590267611 | spiral_5.scad | 225 | 5 | 100 | 28611713 | 171236 | 6143.282715 | 348
2020.05.23 | Intel(R) Xeon(R) Gold 6140 CPU @ 2.30GHz | 1590267611 | spiral_5.scad | 300 | 5 | 100 | 49936859 | 298884 | 8087.174805 | 1636
2020.05.23 | Intel(R) Xeon(R) Gold 6140 CPU @ 2.30GHz | 1590267611 | spiral_5.scad | 47 | 10 | 100 | 4711486 | 28188 | 3602.101562 | 8
2020.05.23 | Intel(R) Xeon(R) Gold 6140 CPU @ 2.30GHz | 1590267611 | spiral_5.scad | 225 | 10 | 100 | 62586579 | 374580 | 12830.408203 | 2973
2020.05.23 | Intel(R) Xeon(R) Gold 6140 CPU @ 2.30GHz | 1590267611 | spiral_5.scad | 300 | 10 | 100 | 106885557 | 639748 | 16717.662109 | 10472
2020.05.23 | Intel(R) Xeon(R) Gold 6140 CPU @ 2.30GHz | 1590267611 | spiral_5.scad | 47 | 20 | 100 | 17063278 | 102092 | 9377.492188 | 99
2020.05.23 | Intel(R) Xeon(R) Gold 6140 CPU @ 2.30GHz | 1590267611 | spiral_5.scad | 225 | 20 | 100 | 148461155 | 888588 | 27832.597656 | 21438
2020.05.23 | Intel(R) Xeon(R) Gold 6140 CPU @ 2.30GHz | 1590462339 | spiral_6.scad | 47 | 1 | 100 | 399526 | 2284 | 1531.221313 | 17
2020.05.23 | Intel(R) Xeon(R) Gold 6140 CPU @ 2.30GHz | 1590462339 | spiral_6.scad | 225 | 1 | 100 | 399526 | 2284 | 1531.221313 | 16
2020.05.23 | Intel(R) Xeon(R) Gold 6140 CPU @ 2.30GHz | 1590462339 | spiral_6.scad | 300 | 1 | 100 | 399526 | 2284 | 1531.221313 | 17
2020.05.23 | Intel(R) Xeon(R) Gold 6140 CPU @ 2.30GHz | 1590462339 | spiral_6.scad | 47 | 2 | 100 | 944798 | 5520 | 3041.062012 | 25
2020.05.23 | Intel(R) Xeon(R) Gold 6140 CPU @ 2.30GHz | 1590462339 | spiral_6.scad | 225 | 2 | 100 | 944798 | 5520 | 3041.062012 | 24
2020.05.23 | Intel(R) Xeon(R) Gold 6140 CPU @ 2.30GHz | 1590462339 | spiral_6.scad | 300 | 2 | 100 | 944798 | 5520 | 3041.062012 | 24
2020.05.23 | Intel(R) Xeon(R) Gold 6140 CPU @ 2.30GHz | 1590462339 | spiral_6.scad | 47 | 5 | 100 | 2215228 | 13102 | 7440.105469 | 53
2020.05.23 | Intel(R) Xeon(R) Gold 6140 CPU @ 2.30GHz | 1590462339 | spiral_6.scad | 225 | 5 | 100 | 2215228 | 13102 | 7440.105469 | 53
2020.05.23 | Intel(R) Xeon(R) Gold 6140 CPU @ 2.30GHz | 1590462339 | spiral_6.scad | 300 | 5 | 100 | 2215228 | 13102 | 7440.105469 | 53
2020.05.23 | Intel(R) Xeon(R) Gold 6140 CPU @ 2.30GHz | 1590462339 | spiral_6.scad | 47 | 10 | 100 | 4265376 | 25396 | 14337.455078 | 120
2020.05.23 | Intel(R) Xeon(R) Gold 6140 CPU @ 2.30GHz | 1590462339 | spiral_6.scad | 225 | 10 | 100 | 4265376 | 25396 | 14337.455078 | 118
2020.05.23 | Intel(R) Xeon(R) Gold 6140 CPU @ 2.30GHz | 1590462339 | spiral_6.scad | 300 | 10 | 100 | 4265376 | 25396 | 14337.455078 | 119
2020.05.23 | Intel(R) Xeon(R) Gold 6140 CPU @ 2.30GHz | 1590462339 | spiral_6.scad | 47 | 20 | 100 | 8466518 | 50584 | 26502.164062 | 415
2020.05.23 | Intel(R) Xeon(R) Gold 6140 CPU @ 2.30GHz | 1590462339 | spiral_6.scad | 225 | 20 | 100 | 8466518 | 50584 | 26502.164062 | 419
2020.05.23 | Intel(R) Xeon(R) Gold 6140 CPU @ 2.30GHz | 1590462339 | spiral_6.scad | 300 | 20 | 100 | 8466518 | 50584 | 26502.164062 | 417
2020.05.23 | Intel(R) Xeon(R) Gold 6140 CPU @ 2.30GHz | 1590462339 | spiral_6.scad | 47 | 40 | 100 | 16479845 | 98572 | 44299.554688 | 1685
2020.05.23 | Intel(R) Xeon(R) Gold 6140 CPU @ 2.30GHz | 1590462339 | spiral_6.scad | 47 | 60 | 100 | 24497881 | 146476 | 53307.937500 | 3943
2020.05.23 | Intel(R) Xeon(R) Gold 6140 CPU @ 2.30GHz | 1590470697 | spiral_7.scad | 47 | 1 | 100 | 122359 | 732 | 259.152863 | 0
2020.05.23 | Intel(R) Xeon(R) Gold 6140 CPU @ 2.30GHz | 1590470697 | spiral_7.scad | 225 | 1 | 100 | 130409 | 780 | 1171.729858 | 0
2020.05.23 | Intel(R) Xeon(R) Gold 6140 CPU @ 2.30GHz | 1590470697 | spiral_7.scad | 300 | 1 | 100 | 131595 | 788 | 1556.410034 | 0
2020.05.23 | Intel(R) Xeon(R) Gold 6140 CPU @ 2.30GHz | 1590470697 | spiral_7.scad | 47 | 2 | 100 | 237560 | 1420 | 542.598877 | 1
2020.05.23 | Intel(R) Xeon(R) Gold 6140 CPU @ 2.30GHz | 1590470697 | spiral_7.scad | 225 | 2 | 100 | 258570 | 1548 | 2377.005127 | 0
2020.05.23 | Intel(R) Xeon(R) Gold 6140 CPU @ 2.30GHz | 1590470697 | spiral_7.scad | 300 | 2 | 100 | 259763 | 1556 | 3149.592285 | 0
2020.05.23 | Intel(R) Xeon(R) Gold 6140 CPU @ 2.30GHz | 1590470697 | spiral_7.scad | 47 | 5 | 100 | 543522 | 3252 | 1521.464355 | 0
2020.05.23 | Intel(R) Xeon(R) Gold 6140 CPU @ 2.30GHz | 1590470697 | spiral_7.scad | 225 | 5 | 100 | 635633 | 3804 | 6121.279297 | 1
2020.05.23 | Intel(R) Xeon(R) Gold 6140 CPU @ 2.30GHz | 1590470697 | spiral_7.scad | 300 | 5 | 100 | 643854 | 3852 | 8059.512695 | 0
2020.05.23 | Intel(R) Xeon(R) Gold 6140 CPU @ 2.30GHz | 1590470697 | spiral_7.scad | 47 | 10 | 100 | 990006 | 5924 | 3581.499756 | 0
2020.05.23 | Intel(R) Xeon(R) Gold 6140 CPU @ 2.30GHz | 1590470697 | spiral_7.scad | 225 | 10 | 100 | 1218352 | 7292 | 12790.331055 | 1
2020.05.23 | Intel(R) Xeon(R) Gold 6140 CPU @ 2.30GHz | 1590470697 | spiral_7.scad | 300 | 10 | 100 | 1247579 | 7468 | 16670.675781 | 1
2020.05.23 | Intel(R) Xeon(R) Gold 6140 CPU @ 2.30GHz | 1590470697 | spiral_7.scad | 47 | 20 | 100 | 1773844 | 10620 | 9307.809570 | 1
2020.05.23 | Intel(R) Xeon(R) Gold 6140 CPU @ 2.30GHz | 1590470697 | spiral_7.scad | 225 | 20 | 100 | 2293750 | 13732 | 27737.871094 | 2
2020.05.23 | Intel(R) Xeon(R) Gold 6140 CPU @ 2.30GHz | 1590470697 | spiral_7.scad | 300 | 20 | 100 | 2364872 | 14156 | 35501.851562 | 2
2020.05.23 | Intel(R) Xeon(R) Gold 6140 CPU @ 2.30GHz | 1590470697 | spiral_7.scad | 47 | 40 | 100 | 3208732 | 19212 | 27181.044922 | 3
2020.05.23 | Intel(R) Xeon(R) Gold 6140 CPU @ 2.30GHz | 1590470697 | spiral_7.scad | 47 | 60 | 100 | 4593813 | 27500 | 53609.050781 | 6
2020.01.17 | Intel(R) Core(TM) i5-4460 CPU @ 3.20GHz | 1590247138 | spiral_1.scad | 47 | 1 | 100 | 600972 | 3336 | 381.905853 | 10
2020.01.17 | Intel(R) Core(TM) i5-4460 CPU @ 3.20GHz | 1590247138 | spiral_1.scad | 225 | 1 | 100 | 803707 | 4492 | 1801.689819 | 11
2020.01.17 | Intel(R) Core(TM) i5-4460 CPU @ 3.20GHz | 1590247138 | spiral_1.scad | 300 | 1 | 100 | 803720 | 4514 | 2399.896240 | 12
2020.01.17 | Intel(R) Core(TM) i5-4460 CPU @ 3.20GHz | 1590247138 | spiral_1.scad | 47 | 2 | 100 | 1208982 | 6706 | 795.789856 | 29
2020.01.17 | Intel(R) Core(TM) i5-4460 CPU @ 3.20GHz | 1590247138 | spiral_1.scad | 225 | 2 | 100 | 1606362 | 8980 | 3621.283447 | 32
2020.01.17 | Intel(R) Core(TM) i5-4460 CPU @ 3.20GHz | 1590247138 | spiral_1.scad | 300 | 2 | 100 | 1647731 | 9242 | 4811.800781 | 31
2020.01.17 | Intel(R) Core(TM) i5-4460 CPU @ 3.20GHz | 1590247138 | spiral_1.scad | 47 | 5 | 100 | 3299087 | 18290 | 2251.598633 | 82
2020.01.17 | Intel(R) Core(TM) i5-4460 CPU @ 3.20GHz | 1590247138 | spiral_1.scad | 225 | 5 | 100 | 4104104 | 22926 | 9294.237305 | 94
2020.01.17 | Intel(R) Core(TM) i5-4460 CPU @ 3.20GHz | 1590247138 | spiral_1.scad | 300 | 5 | 100 | 4080931 | 22910 | 12261.656250 | 97
2020.01.17 | Intel(R) Core(TM) i5-4460 CPU @ 3.20GHz | 1590247138 | spiral_1.scad | 47 | 10 | 100 | 7409653 | 41064 | 5391.819824 | 195
2020.01.17 | Intel(R) Core(TM) i5-4460 CPU @ 3.20GHz | 1590247138 | spiral_1.scad | 225 | 10 | 100 | 8398250 | 46902 | 19462.746094 | 227
2020.01.17 | Intel(R) Core(TM) i5-4460 CPU @ 3.20GHz | 1590247138 | spiral_1.scad | 300 | 10 | 100 | 7985068 | 44890 | 25391.886719 | 222
2020.01.17 | Intel(R) Core(TM) i5-4460 CPU @ 3.20GHz | 1590247138 | spiral_1.scad | 47 | 20 | 100 | 15661917 | 86774 | 14349.493164 | 474
2020.01.17 | Intel(R) Core(TM) i5-4460 CPU @ 3.20GHz | 1590247138 | spiral_1.scad | 225 | 20 | 100 | 16761859 | 93756 | 42476.359375 | 505
2020.01.17 | Intel(R) Core(TM) i5-4460 CPU @ 3.20GHz | 1590247138 | spiral_1.scad | 300 | 20 | 100 | 15509322 | 87376 | 54329.050781 | 488
2020.01.17 | Intel(R) Core(TM) i5-4460 CPU @ 3.20GHz | 1590247138 | spiral_2.scad | 47 | 1 | 100 | 789816 | 4450 | 263.114594 | 13
2020.01.17 | Intel(R) Core(TM) i5-4460 CPU @ 3.20GHz | 1590247138 | spiral_2.scad | 225 | 1 | 100 | 11168654 | 63830 | 1216.354248 | 902
2020.01.17 | Intel(R) Core(TM) i5-4460 CPU @ 3.20GHz | 1590247138 | spiral_2.scad | 300 | 1 | 100 | 16605036 | 95758 | 1616.317383 | 2077
2020.01.17 | Intel(R) Core(TM) i5-4460 CPU @ 3.20GHz | 1590247138 | spiral_2.scad | 47 | 2 | 100 | 1688799 | 9526 | 549.006531 | 33
2020.01.17 | Intel(R) Core(TM) i5-4460 CPU @ 3.20GHz | 1590255352 | spiral_1.scad | 300 | 40 | 100 | 32033323 | 177604 | 42971.972656 | 1114
2020.01.17 | Intel(R) Core(TM) i5-4460 CPU @ 3.20GHz | 1590255352 | spiral_1.scad | 300 | 60 | 100 | 48748311 | 271108 | 85870.351562 | 2291
2020.01.17 | Intel(R) Core(TM) i5-4460 CPU @ 3.20GHz | 1590255352 | spiral_2.scad | 225 | 2 | 100 | 22506308 | 128634 | 2453.479736 | 3759
2020.01.17 | Intel(R) Core(TM) i5-4460 CPU @ 3.20GHz | 1590267568 | spiral_1.scad | 47 | 40 | 100 | 32033323 | 177604 | 42971.980469 | 1258
2020.01.17 | Intel(R) Core(TM) i5-4460 CPU @ 3.20GHz | 1590267568 | spiral_1.scad | 47 | 60 | 100 | 48748311 | 271108 | 85870.320312 | 2572
2020.01.17 | Intel(R) Core(TM) i5-4460 CPU @ 3.20GHz | 1590267568 | spiral_2.scad | 300 | 2 | 100 | 33402178 | 192652 | 3253.252441 | 8697
2020.01.17 | Intel(R) Core(TM) i5-4460 CPU @ 3.20GHz | 1590267568 | spiral_2.scad | 47 | 5 | 100 | 5346893 | 30172 | 1540.823730 | 169
2020.01.17 | Intel(R) Core(TM) i5-4460 CPU @ 3.20GHz | 1590267568 | spiral_2.scad | 225 | 5 | 100 | 57179383 | 327062 | 6297.545410 | 20247
2020.01.17 | Intel(R) Core(TM) i5-4460 CPU @ 3.20GHz | 1590267568 | spiral_2.scad | 300 | 5 | 100 | 83902461 | 484302 | 8296.177734 | 43813
2020.01.17 | Intel(R) Core(TM) i5-4460 CPU @ 3.20GHz | 1590267568 | spiral_2.scad | 47 | 10 | 100 | 15349620 | 86646 | 3639.441162 | 855
2020.01.17 | Intel(R) Core(TM) i5-4460 CPU @ 3.20GHz | 1590267568 | spiral_2.scad | 225 | 10 | 100 |  |  |  | 19198
2020.01.17 | Intel(R) Core(TM) i5-4460 CPU @ 3.20GHz | 1590267568 | spiral_2.scad | 300 | 10 | 100 |  |  |  | 31155
2020.01.17 | Intel(R) Core(TM) i5-4460 CPU @ 3.20GHz | 1590267568 | spiral_2.scad | 47 | 20 | 100 | 53782036 | 304550 | 9501.577148 | 7431
2020.01.17 | Intel(R) Core(TM) i5-4460 CPU @ 3.20GHz | 1590267568 | spiral_2.scad | 225 | 20 | 100 |  |  |  | 25565
2020.01.17 | Intel(R) Core(TM) i5-4460 CPU @ 3.20GHz | 1590267568 | spiral_2.scad | 300 | 20 | 100 |  |  |  | 32681
2020.01.17 | Intel(R) Core(TM) i5-4460 CPU @ 3.20GHz | 1590462435 | spiral_7.scad | 47 | 1 | 100 | 122359 | 732 | 259.152863 | 0
2020.01.17 | Intel(R) Core(TM) i5-4460 CPU @ 3.20GHz | 1590462435 | spiral_7.scad | 225 | 1 | 100 | 130409 | 780 | 1171.729858 | 0
2020.01.17 | Intel(R) Core(TM) i5-4460 CPU @ 3.20GHz | 1590462435 | spiral_7.scad | 300 | 1 | 100 | 131595 | 788 | 1556.410034 | 0
2020.01.17 | Intel(R) Core(TM) i5-4460 CPU @ 3.20GHz | 1590462435 | spiral_7.scad | 47 | 2 | 100 | 237560 | 1420 | 542.598877 | 0
2020.01.17 | Intel(R) Core(TM) i5-4460 CPU @ 3.20GHz | 1590462435 | spiral_7.scad | 225 | 2 | 100 | 258570 | 1548 | 2377.005127 | 0
2020.01.17 | Intel(R) Core(TM) i5-4460 CPU @ 3.20GHz | 1590462435 | spiral_7.scad | 300 | 2 | 100 | 259763 | 1556 | 3149.592285 | 1
2020.01.17 | Intel(R) Core(TM) i5-4460 CPU @ 3.20GHz | 1590462435 | spiral_7.scad | 47 | 5 | 100 | 543522 | 3252 | 1521.464355 | 0
2020.01.17 | Intel(R) Core(TM) i5-4460 CPU @ 3.20GHz | 1590462435 | spiral_7.scad | 225 | 5 | 100 | 635633 | 3804 | 6121.279297 | 0
2020.01.17 | Intel(R) Core(TM) i5-4460 CPU @ 3.20GHz | 1590462435 | spiral_7.scad | 300 | 5 | 100 | 643854 | 3852 | 8059.512695 | 0
2020.01.17 | Intel(R) Core(TM) i5-4460 CPU @ 3.20GHz | 1590462435 | spiral_7.scad | 47 | 10 | 100 | 990006 | 5924 | 3581.499756 | 0
2020.01.17 | Intel(R) Core(TM) i5-4460 CPU @ 3.20GHz | 1590462435 | spiral_7.scad | 225 | 10 | 100 | 1218352 | 7292 | 12790.331055 | 1
2020.01.17 | Intel(R) Core(TM) i5-4460 CPU @ 3.20GHz | 1590462435 | spiral_7.scad | 300 | 10 | 100 | 1247579 | 7468 | 16670.675781 | 1
2020.01.17 | Intel(R) Core(TM) i5-4460 CPU @ 3.20GHz | 1590462435 | spiral_7.scad | 47 | 20 | 100 | 1773844 | 10620 | 9307.809570 | 1
2020.01.17 | Intel(R) Core(TM) i5-4460 CPU @ 3.20GHz | 1590462435 | spiral_7.scad | 225 | 20 | 100 | 2293750 | 13732 | 27737.871094 | 2
2020.01.17 | Intel(R) Core(TM) i5-4460 CPU @ 3.20GHz | 1590462435 | spiral_7.scad | 300 | 20 | 100 | 2364872 | 14156 | 35501.851562 | 2
2020.01.17 | Intel(R) Core(TM) i5-4460 CPU @ 3.20GHz | 1590462435 | spiral_7.scad | 47 | 40 | 100 | 3208732 | 19212 | 27181.044922 | 3
2020.01.17 | Intel(R) Core(TM) i5-4460 CPU @ 3.20GHz | 1590462435 | spiral_7.scad | 47 | 60 | 100 | 4593813 | 27500 | 53609.050781 | 6
2019.05 | Intel(R) Core(TM) i7-4770HQ CPU @ 2.20GHz | 1590194549 | spiral_1.scad | 47 | 1 | 100 | 600972 | 3336 | 381.906097 | 40
2019.05 | Intel(R) Core(TM) i7-4770HQ CPU @ 2.20GHz | 1590194549 | spiral_1.scad | 225 | 1 | 100 | 803707 | 4492 | 1801.691162 | 51
2019.05 | Intel(R) Core(TM) i7-4770HQ CPU @ 2.20GHz | 1590194549 | spiral_1.scad | 300 | 1 | 100 | 803720 | 4514 | 2399.895996 | 52
2019.05 | Intel(R) Core(TM) i7-4770HQ CPU @ 2.20GHz | 1590194549 | spiral_1.scad | 47 | 2 | 100 | 1208982 | 6706 | 795.789307 | 115
2019.05 | Intel(R) Core(TM) i7-4770HQ CPU @ 2.20GHz | 1590194549 | spiral_1.scad | 225 | 2 | 100 | 1606362 | 8980 | 3621.289551 | 153
2019.05 | Intel(R) Core(TM) i7-4770HQ CPU @ 2.20GHz | 1590194549 | spiral_1.scad | 300 | 2 | 100 | 1647731 | 9242 | 4811.799805 | 160
2019.05 | Intel(R) Core(TM) i7-4770HQ CPU @ 2.20GHz | 1590194549 | spiral_1.scad | 47 | 5 | 100 | 3299087 | 18290 | 2251.602051 | 354
2019.05 | Intel(R) Core(TM) i7-4770HQ CPU @ 2.20GHz | 1590194549 | spiral_1.scad | 225 | 5 | 100 | 4104104 | 22926 | 9294.230469 | 464
2019.05 | Intel(R) Core(TM) i7-4770HQ CPU @ 2.20GHz | 1590194549 | spiral_1.scad | 300 | 5 | 100 | 4080931 | 22910 | 12261.718750 | 442
2019.05 | Intel(R) Core(TM) i7-4770HQ CPU @ 2.20GHz | 1590194549 | spiral_1.scad | 47 | 10 | 100 | 7409653 | 41064 | 5391.789551 | 886
2019.05 | Intel(R) Core(TM) i7-4770HQ CPU @ 2.20GHz | 1590194549 | spiral_1.scad | 225 | 10 | 100 | 8398250 | 46902 | 19462.830078 | 1066
2019.05 | Intel(R) Core(TM) i7-4770HQ CPU @ 2.20GHz | 1590194549 | spiral_1.scad | 300 | 10 | 100 | 7985068 | 44890 | 25391.851562 | 1042
2019.05 | Intel(R) Core(TM) i7-4770HQ CPU @ 2.20GHz | 1590194549 | spiral_1.scad | 47 | 20 | 100 | 15661917 | 86774 | 14349.436523 | 2117
2019.05 | Intel(R) Core(TM) i7-4770HQ CPU @ 2.20GHz | 1590194549 | spiral_1.scad | 225 | 20 | 100 | 16761859 | 93756 | 42476.585938 | 2594
2019.05 | Intel(R) Core(TM) i7-4770HQ CPU @ 2.20GHz | 1590194549 | spiral_1.scad | 300 | 20 | 100 | 15509327 | 87376 | 54329.039062 | 2398
2019.05 | Intel(R) Core(TM) i7-4770HQ CPU @ 2.20GHz | 1590194549 | spiral_2.scad | 47 | 1 | 100 | 789816 | 4450 | 263.114410 | 51
2019.05 | Intel(R) Core(TM) i7-4770HQ CPU @ 2.20GHz | 1590194549 | spiral_2.scad | 225 | 1 | 100 | 11168654 | 63830 | 1216.367676 | 2405
2019.05 | Intel(R) Core(TM) i7-4770HQ CPU @ 2.20GHz | 1590194549 | spiral_2.scad | 300 | 1 | 100 | 16605036 | 95758 | 1616.315308 | 5083
2019.05 | Intel(R) Core(TM) i7-4770HQ CPU @ 2.20GHz | 1590194549 | spiral_2.scad | 47 | 2 | 100 | 1688799 | 9526 | 549.007080 | 124
2019.05 | Intel(R) Core(TM) i7-4770HQ CPU @ 2.20GHz | 1590194549 | spiral_2.scad | 225 | 2 | 100 | 22506308 | 128634 | 2453.499268 | 6582
2019.05 | Intel(R) Core(TM) i7-4770HQ CPU @ 2.20GHz | 1590194549 | spiral_2.scad | 300 | 2 | 100 | 33402178 | 192652 | 3253.312744 | 14361
2019.05 | Intel(R) Core(TM) i7-4770HQ CPU @ 2.20GHz | 1590194549 | spiral_2.scad | 47 | 5 | 100 | 5346893 | 30172 | 1540.825195 | 527
2019.05 | Intel(R) Core(TM) i7-4770HQ CPU @ 2.20GHz | 1590267749 | spiral_1.scad | 47 | 40 | 100 | 32033323 | 177604 | 42971.632812 | 5694
2019.05 | Intel(R) Core(TM) i7-4770HQ CPU @ 2.20GHz | 1590267749 | spiral_1.scad | 47 | 60 | 100 | 48748311 | 271108 | 85870.750000 | 11370
2019.05 | Intel(R) Core(TM) i7-4770HQ CPU @ 2.20GHz | 1590267749 | spiral_2.scad | 225 | 5 | 100 | 57179383 | 327062 | 6297.617188 | 35406
2019.05 | Intel(R) Core(TM) i7-4770HQ CPU @ 2.20GHz | 1590267749 | spiral_2.scad | 300 | 5 | 100 | 83902461 | 484302 | 8297.022461 | 70436
2019.05 | Intel(R) Core(TM) i7-4770HQ CPU @ 2.20GHz | 1590267749 | spiral_2.scad | 47 | 10 | 100 | 15349620 | 86646 | 3639.449707 | 2305
2019.05 | Intel(R) Core(TM) i7-4770HQ CPU @ 2.20GHz | 1590423791 | spiral_3.scad | 47 | 1 | 100 | 134313 | 804 | 262.170135 | 0
2019.05 | Intel(R) Core(TM) i7-4770HQ CPU @ 2.20GHz | 1590423791 | spiral_3.scad | 225 | 1 | 100 | 134269 | 804 | 1183.955444 | 0
2019.05 | Intel(R) Core(TM) i7-4770HQ CPU @ 2.20GHz | 1590423791 | spiral_3.scad | 300 | 1 | 100 | 134365 | 804 | 1572.317627 | 0
2019.05 | Intel(R) Core(TM) i7-4770HQ CPU @ 2.20GHz | 1590423791 | spiral_3.scad | 47 | 2 | 100 | 267846 | 1604 | 545.908936 | 0
2019.05 | Intel(R) Core(TM) i7-4770HQ CPU @ 2.20GHz | 1590423791 | spiral_3.scad | 225 | 2 | 100 | 267837 | 1604 | 2389.486816 | 1
2019.05 | Intel(R) Core(TM) i7-4770HQ CPU @ 2.20GHz | 1590423791 | spiral_3.scad | 300 | 2 | 100 | 268195 | 1604 | 3166.378174 | 0
2019.05 | Intel(R) Core(TM) i7-4770HQ CPU @ 2.20GHz | 1590423791 | spiral_3.scad | 47 | 5 | 100 | 668359 | 4004 | 1526.071045 | 1
2019.05 | Intel(R) Core(TM) i7-4770HQ CPU @ 2.20GHz | 1590423791 | spiral_3.scad | 225 | 5 | 100 | 668390 | 4004 | 6134.965332 | 0
2019.05 | Intel(R) Core(TM) i7-4770HQ CPU @ 2.20GHz | 1590423791 | spiral_3.scad | 300 | 5 | 100 | 669164 | 4004 | 8077.240723 | 1
2019.05 | Intel(R) Core(TM) i7-4770HQ CPU @ 2.20GHz | 1590423791 | spiral_3.scad | 47 | 10 | 100 | 1336635 | 8004 | 3589.485596 | 1
2019.05 | Intel(R) Core(TM) i7-4770HQ CPU @ 2.20GHz | 1590423791 | spiral_3.scad | 225 | 10 | 100 | 1336668 | 8004 | 12807.394531 | 1
2019.05 | Intel(R) Core(TM) i7-4770HQ CPU @ 2.20GHz | 1590423791 | spiral_3.scad | 300 | 10 | 100 | 1337659 | 8004 | 16691.759766 | 1
2019.05 | Intel(R) Core(TM) i7-4770HQ CPU @ 2.20GHz | 1590423791 | spiral_3.scad | 47 | 20 | 100 | 2673096 | 16004 | 9328.120117 | 3
2019.05 | Intel(R) Core(TM) i7-4770HQ CPU @ 2.20GHz | 1590423791 | spiral_3.scad | 225 | 20 | 100 | 2673089 | 16004 | 27763.302734 | 3
2019.05 | Intel(R) Core(TM) i7-4770HQ CPU @ 2.20GHz | 1590423791 | spiral_3.scad | 300 | 20 | 100 | 2674182 | 16004 | 35531.792969 | 3
2019.05 | Intel(R) Core(TM) i7-4770HQ CPU @ 2.20GHz | 1590423791 | spiral_3.scad | 47 | 40 | 100 | 5346008 | 32004 | 27252.826172 | 9
2019.05 | Intel(R) Core(TM) i7-4770HQ CPU @ 2.20GHz | 1590423791 | spiral_3.scad | 47 | 60 | 100 | 8019095 | 48004 | 53773.640625 | 18
2019.05 | Intel(R) Core(TM) i7-4770HQ CPU @ 2.20GHz | 1590423791 | spiral_4.scad | 47 | 1 | 100 | 79570 | 476 | 283.918793 | 0
2019.05 | Intel(R) Core(TM) i7-4770HQ CPU @ 2.20GHz | 1590423791 | spiral_4.scad | 225 | 1 | 100 | 1774211 | 10620 | 1264.982422 | 1
2019.05 | Intel(R) Core(TM) i7-4770HQ CPU @ 2.20GHz | 1590423791 | spiral_4.scad | 300 | 1 | 100 | 3152086 | 18868 | 1679.437256 | 3
2019.05 | Intel(R) Core(TM) i7-4770HQ CPU @ 2.20GHz | 1590423791 | spiral_4.scad | 47 | 2 | 100 | 175601 | 1052 | 585.684998 | 2
2019.05 | Intel(R) Core(TM) i7-4770HQ CPU @ 2.20GHz | 1590423791 | spiral_4.scad | 225 | 2 | 100 | 3611465 | 21636 | 2551.926025 | 140
2019.05 | Intel(R) Core(TM) i7-4770HQ CPU @ 2.20GHz | 1590423791 | spiral_4.scad | 300 | 2 | 100 | 6386412 | 38260 | 3381.085693 | 386
2019.05 | Intel(R) Core(TM) i7-4770HQ CPU @ 2.20GHz | 1590423791 | spiral_4.scad | 47 | 5 | 100 | 561609 | 3362 | 1629.687744 | 13
2019.05 | Intel(R) Core(TM) i7-4770HQ CPU @ 2.20GHz | 1590423791 | spiral_4.scad | 225 | 5 | 100 | 9536133 | 57130 | 6550.490234 | 1288
2019.05 | Intel(R) Core(TM) i7-4770HQ CPU @ 2.20GHz | 1590423791 | spiral_4.scad | 300 | 5 | 100 | 16636338 | 99668 | 8623.678711 | 3987
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

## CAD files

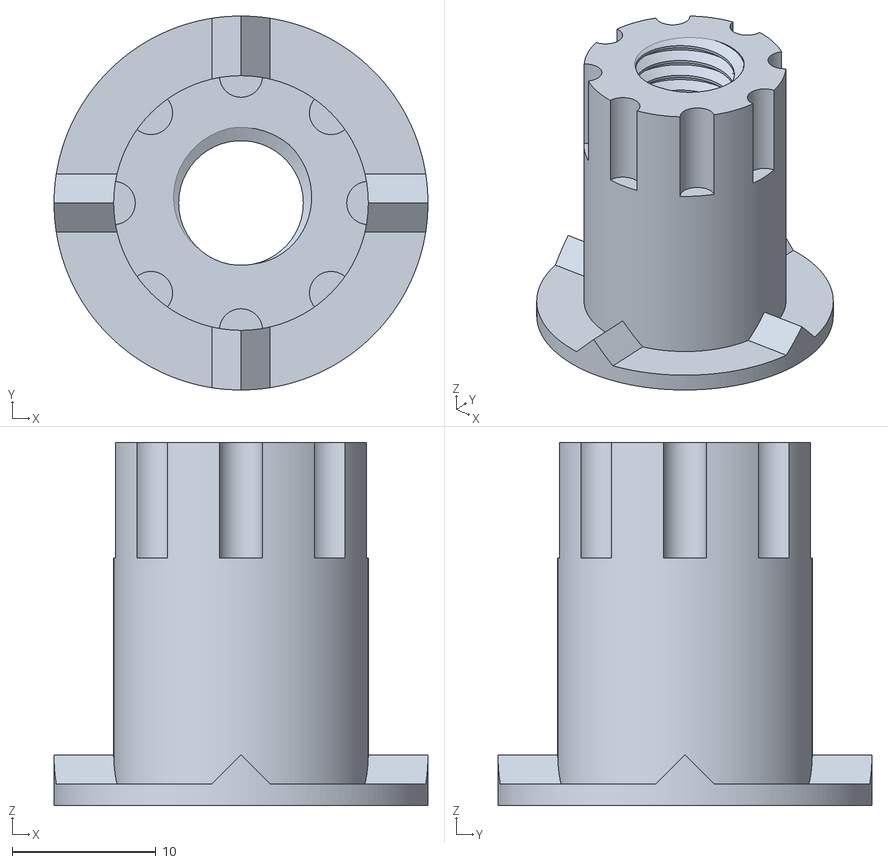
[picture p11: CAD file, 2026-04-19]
stl/100ft_v3/gnal_100ft_insert_16.stl
26.0 x 26.0 x 25.2

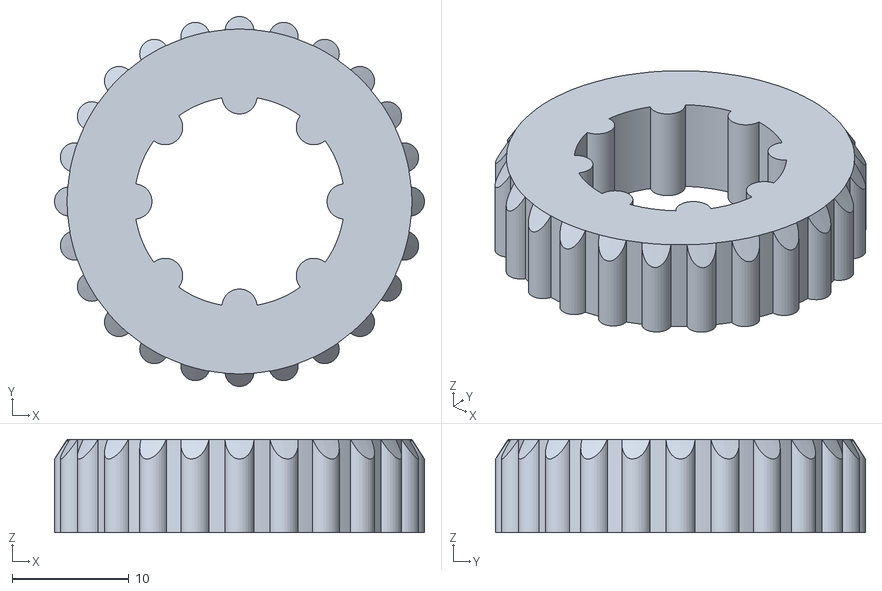
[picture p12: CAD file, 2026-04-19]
stl/50ft_v3/gnal_50ft_spacer_16.stl
31.7 x 31.7 x 8.00

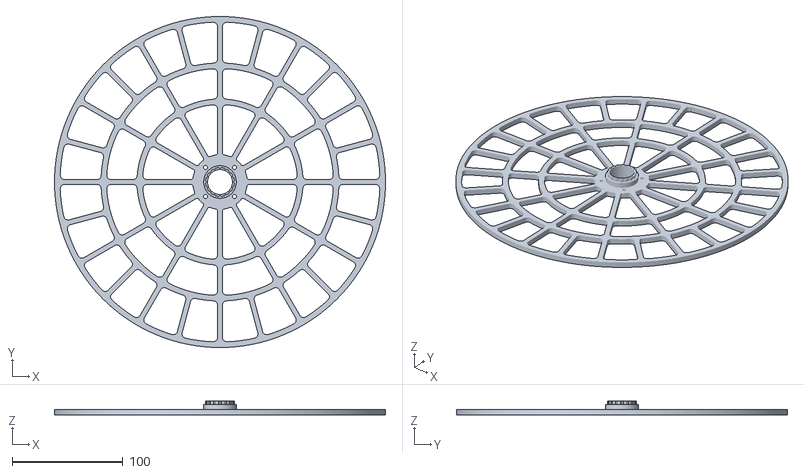
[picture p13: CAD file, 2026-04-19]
stl/100ft_v3/gnal_100ft_top.stl
299.0 x 299.0 x 12.9

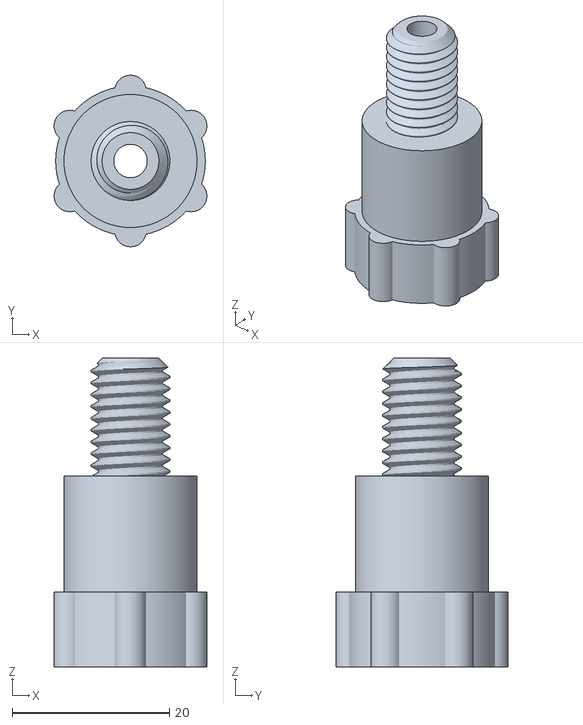
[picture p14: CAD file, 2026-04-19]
stl/50ft_v3/gnal_50ft_spindle_bottom_reinforced.stl
19.4 x 21.8 x 39.2

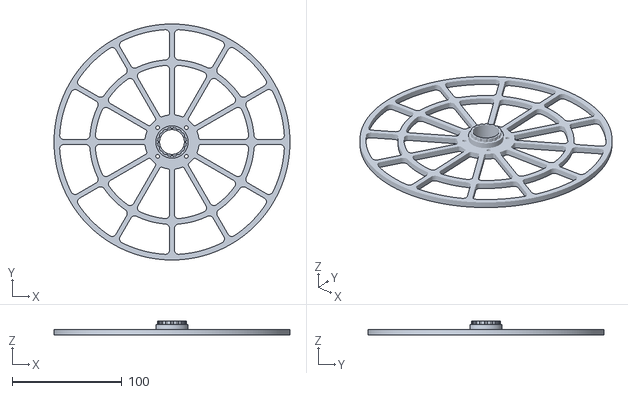
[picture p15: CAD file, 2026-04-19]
stl/50ft_v3/gnal_50ft_top.stl
215.0 x 215.0 x 12.9

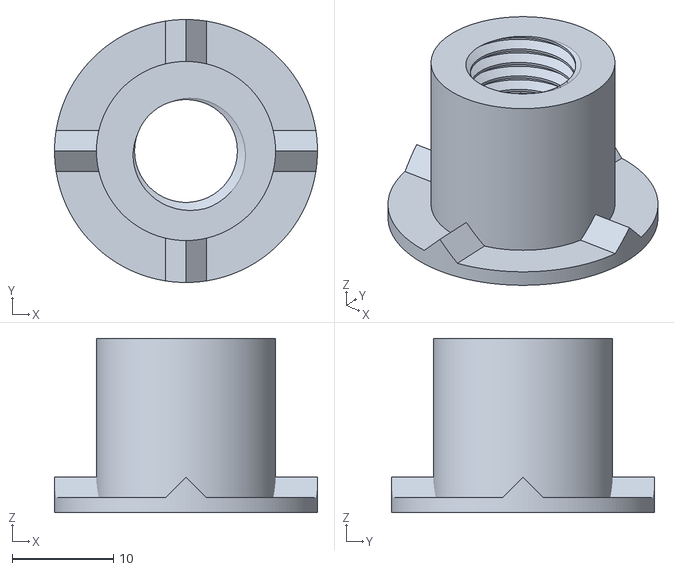
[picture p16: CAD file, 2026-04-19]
stl/100ft_v3/gnal_100ft_insert_single.stl
26.0 x 26.0 x 17.2

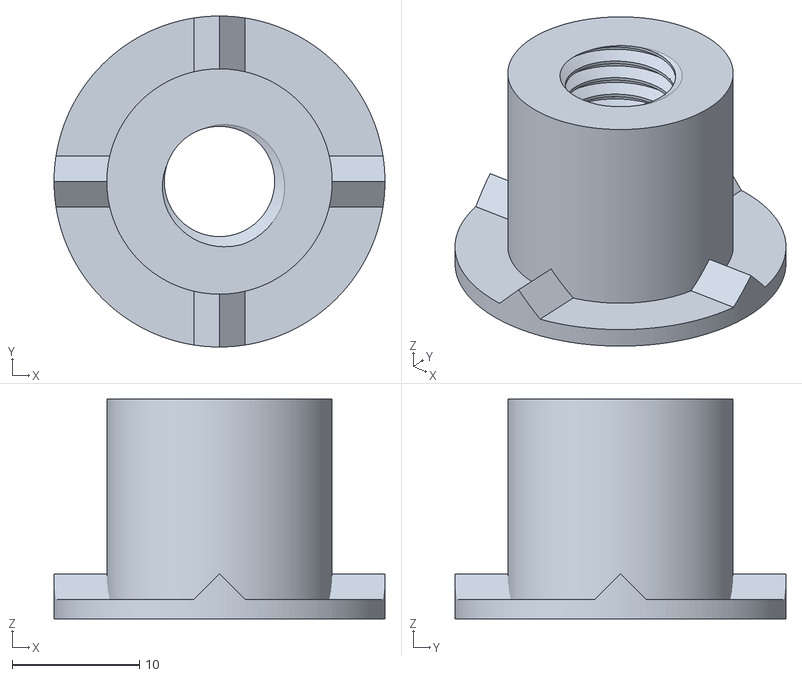
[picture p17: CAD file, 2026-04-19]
stl/50ft_v3/gnal_50ft_insert_s8.stl
26.0 x 26.0 x 17.2

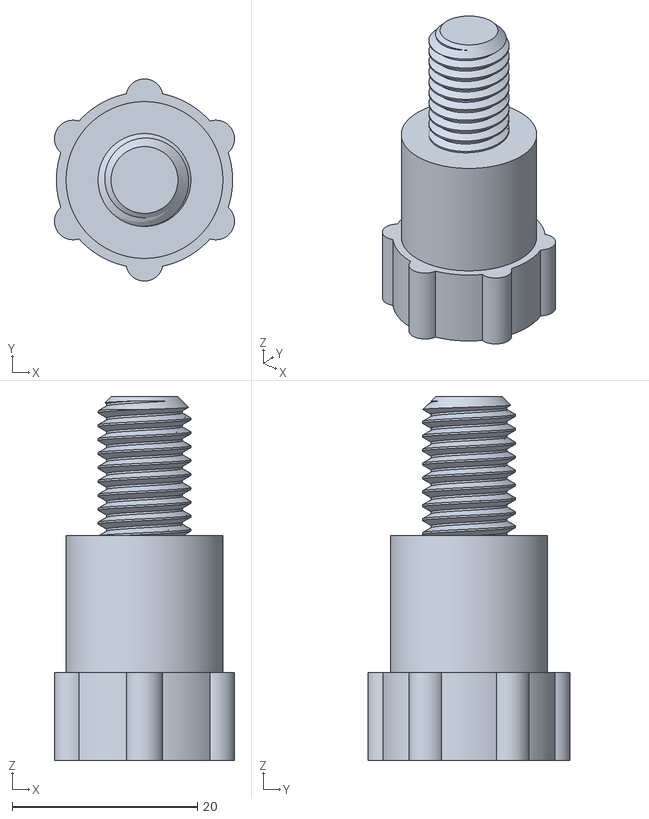
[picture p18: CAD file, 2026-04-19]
stl/100ft_v3/gnal_100ft_spindle_bottom.stl
19.4 x 21.8 x 39.2

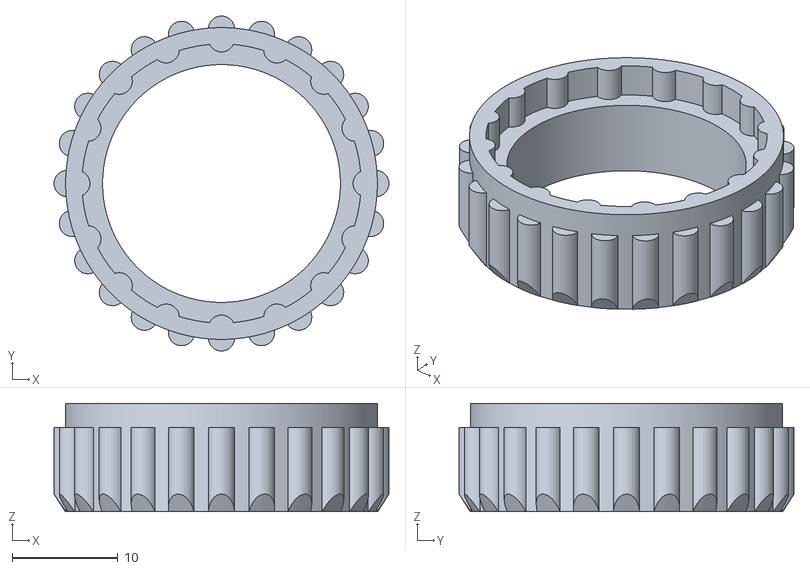
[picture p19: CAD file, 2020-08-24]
stl/100ft_v3/gnal_100ft_spacer.stl
31.7 x 31.7 x 10.2

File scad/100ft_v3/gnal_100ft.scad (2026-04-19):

//V3

include <../libraries/gnal_v3.scad>;

SPOKE_COUNT = 24;

module gnal_100ft_spiral (spiral_count = 60, od = 298.75, quarter = false) {
    outer_d = 299;
    outer_d_inside = outer_d - 6;
    outer_h = 7.5;
    
    spoke_len = 123;
    spoke_w = 3;
    spoke_h = 4.2 + 3;
    
    spoke_2_len = 85;
    
    spoke_cross_1_d = 63;
    spoke_cross_1_w = 18;
    
    spoke_cross_2_d = 108;
    spoke_cross_2_w = 15;
    
    spoke_3_len = 39;
    spoke_3_w = 2;
    
    translate([0, 0, -3.6]) difference () {
        cylinder(r = outer_d / 2, h = spoke_h, center = true, $fn = 500);
        cylinder(r = outer_d_inside / 2, h = outer_h + 1, center = true, $fn = 500);
    }
    
    difference () {
        gnal_spiral_core();
        //rounded spoke voids
        for (i = [0 : SPOKE_COUNT - 1]) {
            rotate([0, 0, (i + 0.5) * (360 / SPOKE_COUNT)]) {
                translate([0, 26.75, 0]) {
                    cylinder(r = 2, h = 20, center = true, $fn = 40);
                }
            }
        }
    }
    
    //main spokes
    for (i = [0 : SPOKE_COUNT - 1]) {
        rotate([0, 0, i * (360 / SPOKE_COUNT)]) {
            translate([(spoke_len / 2) + (48 / 2), 0, -3.6]) {
                if (quarter && i % 3 == 0 && i % 6 != 0) { //phew!
                    cube([spoke_len, spoke_w * 2, spoke_h], center = true);
                } else {
                    cube([spoke_len, spoke_w, spoke_h], center = true);
                }
            }
        }
    }
    //secondary spokes
    for (i = [0 : SPOKE_COUNT - 1]) {
        rotate([0, 0, (i + 0.5) * (360 / SPOKE_COUNT)]) {
            translate([(outer_d / 2) - (spoke_2_len / 2) - 2, 0, -3.6]) {
                cube([spoke_2_len, spoke_w, spoke_h], center = true);
            }
        }
    }
    //spoke cross bars
    for (i = [0 : SPOKE_COUNT - 1]) {
        rotate([0, 0, (i + 0.5) * (360 / SPOKE_COUNT)]) {
            translate([63, 0, -3.6]) {
                rotate([0, 0, 20]) {
                    cube([ spoke_w, 18, spoke_h], center = true);
                }
            }
        }
    }
    
    //second spokes
    for (i = [0 : SPOKE_COUNT - 1]) {
        rotate([0, 0, (i + 0.5) * (360 / SPOKE_COUNT)]) {
            translate([(outer_d / 2) - (spoke_2_len / 2) - 2, 0, -3.6]) {
                cube([spoke_2_len, spoke_w, spoke_h], center = true);
            }
        }
    }

    //second spoke cross pieces
    for (i = [0 : (SPOKE_COUNT * 2) - 1]) {
        rotate([0, 0, (i + 0.5) * (360 / (SPOKE_COUNT * 2))]) {
            translate([spoke_cross_2_d, 0, -3.6]) {
                rotate([0, 0, -20]) {
                    cube([ spoke_w, spoke_cross_2_w, spoke_h], center = true);
                }
            }
        }
    }
    
    //third spokes
    for (i = [0 : (SPOKE_COUNT * 2) - 1]) {
        rotate([0, 0, (i + 0.5) * (360 / (SPOKE_COUNT * 2))]) {
            translate([(outer_d / 2) - (spoke_3_len / 2) - 2, 0, -3.6]) {
                cube([spoke_3_len, spoke_3_w, spoke_h], center = true);
            }
        }
    }

    translate([0, 0, -.1]) {
        rotate([0, 0, -90]) {
            film_guide(spiral_count);
        }
    }
}

module gnal_100ft_spiral_quarter (quarter = "a") {
    LEN = 220;

    module notch (NOTCH = 5) {
        cube([NOTCH, NOTCH, 5], center = true);
        translate([0, 0, (5 / 2) + (1 / 2)]) rotate([0, 0, 45]) cylinder(r1 = NOTCH / 1.4, r2 = 0.1, h = 1, center = true, $fn = 4);
    }
    
    module quarter () {
        NOTCH = 3;
        NOTCH_H = -5;
        NOTCHES = 7;
        OFFSET = 60;
        difference () {
            cube([LEN, LEN, LEN], center = true);
            for (i = [0 : NOTCHES - 1]) {
                translate([OFFSET - (i * (LEN / NOTCHES)), -(LEN / 2), NOTCH_H]) rotate([0, 0, 45]) notch(NOTCH);
            }
        }
        for (i = [0 : NOTCHES - 2]) {
            translate([-(LEN / 2), OFFSET - (i * (LEN / NOTCHES)), NOTCH_H]) rotate([0, 0, 45]) notch(NOTCH);
        }
    }

    intersection () {
        rotate([0, 0, 45]) gnal_100ft_spiral(quarter = true);
        if (quarter == "a") {
            rotate([0, 0, 0]) translate([LEN / 2, LEN / 2, 0]) quarter();
        } else if (quarter == "b") {
            rotate([0, 0, 90]) translate([LEN / 2, LEN / 2, 0]) quarter();
        } else if (quarter == "c") {
            rotate([0, 0, 180]) translate([LEN / 2, LEN / 2, 0]) quarter();
        } else if (quarter == "d") {
            rotate([0, 0, 270]) translate([LEN / 2, LEN / 2, 0]) quarter();
        }
    }
}
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

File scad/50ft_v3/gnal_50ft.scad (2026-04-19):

//V3

include <../libraries/gnal_v3.scad>;

SPOKE_COUNT = 24;

module gnal_50ft_spiral (spiral_count = 40, od = 215.75, quarter = false) {
    outer_d = 215;
    outer_d_inside = 209;
    outer_h = 7.5;
    
    spoke_len = 81;
    spoke_w = 3;
    spoke_h = 4.2 + 3;
    
    spoke_2_len = 43;
    
    translate([0, 0, -3.6]) difference () {
        cylinder(r = outer_d / 2, h = spoke_h, center = true, $fn = 500);
        cylinder(r = outer_d_inside / 2, h = outer_h + 1, center = true, $fn = 500);
    }
    
    difference () {
        gnal_spiral_core();
        //rounded spoke voids
        for (i = [0 : SPOKE_COUNT]) {
            rotate([0, 0, (i + 0.5) * (360 / SPOKE_COUNT)]) {
                translate([0, 26.75, 0]) {
                    cylinder(r = 2, h = 20, center = true, $fn = 40);
                }
            }
        }
    }
    //main spokes
    for (i = [0 : SPOKE_COUNT]) {
        rotate([0, 0, i * (360 / SPOKE_COUNT)]) {
            translate([(spoke_len / 2) + (48 / 2), 0, -3.6]) {
                if (quarter && i % 3 == 0 && i % 6 != 0) { //phew!
                    cube([spoke_len, spoke_w * 2, spoke_h], center = true);
                } else {
                    cube([spoke_len, spoke_w, spoke_h], center = true);
                }
            }
        }
    }
    //secondary spokes
    for (i = [0 : SPOKE_COUNT]) {
        rotate([0, 0, (i + 0.5) * (360 / SPOKE_COUNT)]) {
            translate([(outer_d / 2) - (spoke_2_len / 2) - 2, 0, -3.6]) {
                cube([spoke_2_len, spoke_w, spoke_h], center = true);
            }
        }
    }
    //spoke cross bars
    for (i = [0 : SPOKE_COUNT]) {
        rotate([0, 0, (i + 0.5) * (360 / SPOKE_COUNT)]) {
            translate([63, 0, -3.6]) {
                rotate([0, 0, 20]) {
                    cube([ spoke_w, 18, spoke_h], center = true);
                }
            }
        }
    }
    
    translate([0, 0, -.1]) {
        rotate([0, 0, -90]) {
            film_guide(spiral_count);
        }
    }
}

module gnal_50ft_spiral_quarter (quarter = "a") {
    LEN = 220;
    module notch (NOTCH = 5) {
        cube([NOTCH, NOTCH, 5], center = true);
        translate([0, 0, (5 / 2) + (1 / 2)]) rotate([0, 0, 45]) cylinder(r1 = NOTCH / 1.4, r2 = 0.1, h = 1, center = true, $fn = 4);
    }
    
    module quarter () {
        NOTCH = 3;
        NOTCH_H = -5;
        NOTCHES = 7;
        OFFSET = 60;
        difference () {
            cube([LEN, LEN, LEN], center = true);
            for (i = [0 : NOTCHES - 1]) {
                translate([OFFSET - (i * (LEN / NOTCHES)), -(LEN / 2), NOTCH_H]) rotate([0, 0, 45]) notch(NOTCH);
            }
        }
        for (i = [0 : NOTCHES - 2]) {
            translate([-(LEN / 2), OFFSET - (i * (LEN / NOTCHES)), NOTCH_H]) rotate([0, 0, 45]) notch(NOTCH);
        }
    }
    intersection () {
        rotate([0, 0, 45]) gnal_50ft_spiral(quarter = true);
        if (quarter == "a") {
            rotate([0, 0, 0]) translate([LEN / 2, LEN / 2, 0]) quarter();
        } else if (quarter == "b") {
            rotate([0, 0, 90]) translate([LEN / 2, LEN / 2, 0]) quarter();
        } else if (quarter == "c") {
            rotate([0, 0, 180]) translate([LEN / 2, LEN / 2, 0]) quarter();
        } else if (quarter == "d") {
            rotate([0, 0, 270]) translate([LEN / 2, LEN / 2, 0]) quarter();
        }
    }
}

module gnal_50ft_top () {
    H = 5;
    center_d = 53;
    spoke_w = 4.5;
    spokes = 12;
    outer_d = 215;
    inner_d = 150;
    void_d = 22.5;
    hole_d = 3.5;
    hole_spacing = 37;
    core_d = 29.5;
    core_bottom_d = 26.2;
    
    difference () {
        union () {
            cylinder(r = center_d / 2, h = H, center = true, $fn = 100);
            for (i = [0 : spokes - 1]) {
                rotate([0, 0, i * (360 / spokes)]) translate([0, outer_d / 4, 0]) cube([spoke_w, (outer_d / 2) - 1, H], center = true);
            }
        }
        //void
        cylinder(r = void_d / 2, h = H + 1, center = true, $fn = 100);
        //speed holes
        for (i = [0 : 3]) {
            rotate([0, 0, (i * 90) + 45]) translate([0, hole_spacing / 2, 0]) cylinder(r = hole_d / 2, h = H + 1, center = true);
        }
        //rounding of center cylinder
        for (i = [0 : spokes - 1]) {
            rotate([0, 0, (i + 0.5) * (360 / spokes)]) translate([-2.75, 26.5, 0]) cylinder(r = 2, h = H+1, center = true, $fn = 40);
            rotate([0, 0, (i + 0.5) * (360 / spokes)]) translate([2.75, 26.5, 0]) cylinder(r = 2, h = H+1, center = true, $fn = 40);
            rotate([0, 0, (i + 0.5) * (360 / spokes)]) translate([0, 26.5, 0]) cube([5, 4, H + 1], center = true);
        }
    }
    difference () {
        cylinder(r = (center_d / 2) - 1.8, h = H, center = true, $fn = 200);
        cylinder(r = (hole_spacing / 2) + 2, h = H + 1, center = true, $fn = 200);
    }
    //outer ring
    difference () {
        cylinder(r = outer_d / 2, h = H, center = true, $fn = 200);
        cylinder(r = (outer_d / 2) - 5, h = H + 1, center = true, $fn = 200);
    }
    //inner ring
    difference () {
        cylinder(r = inner_d / 2, h = H, center = true, $fn = 200);
        cylinder(r = (inner_d / 2) - 5, h = H + 1, center = true, $fn = 200);
    }
    //rounded cross connectors
    for (i = [0 : spokes - 1]) {
        rotate([0, 0, i * (360 / spokes)]) translate([0, (inner_d / 2) - (spoke_w / 2), 0]) difference() {
            cylinder(r = 6.5, h = H, center = true);
            translate([6.25, 6, 0]) cylinder(r = 4, h = H + 1, center = true, $fn = 60);
            translate([-6.25, 6, 0]) cylinder(r = 4, h = H + 1, center = true, $fn = 60);
            translate([-6.1, -7, 0]) cylinder(r = 4, h = H + 1, center = true, $fn = 60);
            translate([6.1, -7, 0]) cylinder(r = 4, h = H + 1, center = true, $fn = 60);
        }
    }
    difference () {
        union () {
            translate([0, 0, 3.75 + 1]) cylinder(r = core_d / 2, h = H, center = true, $fn = 60);
            translate([0, 0, 3.75 + 1 + 3.2]) cylinder(r = core_bottom_d / 2, h = H, center = true, $fn = 60);
        }
        cylinder(r = void_d / 2, h = H * 5 , center = true, $fn = 100);
        translate([0, 0, 4 + 1 + 2.25]) spacer_ridges();
    }
    //rounded outer ring connectors
    for (i = [0 : spokes - 1]) {
        rotate([0, 0, i * (360 / spokes)]) translate([0, 205 / 2, 0]) difference () {
            cube([13, 9, H], center = true);
            translate([6.2, -4.2, 0]) cylinder(r = 4, h = H + 1, center = true, $fn = 60);
            translate([-6.2, -4.2, 0]) cylinder(r = 4, h = H + 1, center = true, $fn = 60);
        }
    }        
}

FN = 200;
$fn = FN;

module film_guide (rotations = 40, id = 45.55 - .5, spacing = 2.075, bottom = -2) {
    spiral(rotations, id, spacing, bottom, $fn);
}

PART="spindle_top_reinforced";

if (PART == "spiral") {
    gnal_50ft_spiral();
} else if (PART == "quarter_a") {
    gnal_50ft_spiral_quarter("a");
} else if (PART == "quarter_b") {
    gnal_50ft_spiral_quarter("b");
} else if (PART == "quarter_c") {
    gnal_50ft_spiral_quarter("c");
} else if (PART == "quarter_d") {
    gnal_50ft_spiral_quarter("d");
} else if (PART == "top") {
    gnal_50ft_top();
} else if (PART == "spacer") {
    gnal_spacer();
} else if (PART == "insert_s8") {
    gnal_spiral_bottom_insert_s8();
} else if (PART == "insert_16") {
    gnal_spiral_bottom_insert_16();
} else if (PART == "insert_single") {
    gnal_spiral_bottom_insert_single();
} else if (PART == "spacer_16") {
    gnal_spacer_16();
} else if (PART == "spindle_top") {
    gnal_spindle_top();
} else if (PART == "spindle_top_reinforced") {
    gnal_spindle_top(reinforced = true);
} else if (PART == "spindle_bottom") {
    gnal_spindle_bottom();
} else if (PART == "spindle_bottom_reinforced") {
    gnal_spindle_bottom(reinforced = true);
} else if (PART == "spindle_single") {
    gnal_spindle_top();
} else if (PART == "spiral_test") {
    difference () {
        gnal_50ft_spiral();
        translate([125, 0, 0]) cube([250, 250, 100], center = true);
        rotate([0, 0, 30]) translate([-125, 0, 0]) cube([250, 250, 100], center = true);
    }
}

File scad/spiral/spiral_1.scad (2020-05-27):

D=300; // start diameter
N=1;   // number of spirals
FN=100;
$fn=FN;


H = 2.1;

/**
 * Render all spiral facets for as many rotations as supplied
 */
module spiral (START_D = 50, SPIRALS = 39) {
    //STOP_D = 100;
  
    SPACING = 0.86;//1.34;
  
  	TOP_T = 0.86; //thickness
  	BOTTOM_T = 1.4;
  
  	START_R = START_D / 2;
    union () {
        for (i = [0 : $fn]) {
            rotate ([0, 0, i * (360 / $fn)]) {
                for (x = [0: (SPIRALS - 1)]) {
                      spiral_facet(i, x, START_R, SPACING, BOTTOM_T, TOP_T, H);
                }
            }
        }
    }
}

/**
 * Generates a single face of the spiral, in this case a trapazoidal
 * shape. Issues are (1) performance (maybe use of hull()) and (2) all
 * facet counts are the same, despite the diameter. This means that
 * there are excessive numbers of facets for the smaller spirals to
 * compensate for the number of facets needed for the outer spiral.
 */

module spiral_facet (i, x, START_R, SPACING, BOTTOM_T, TOP_T, H) {
    STEP_SIZE = ((SPACING + BOTTOM_T) / $fn); 
    
    STEP_OFFSET =  i * STEP_SIZE;
    SPIRAL_START_OFFSET = (x * (SPACING + BOTTOM_T));
    
    ACTUAL_R = START_R + SPIRAL_START_OFFSET + STEP_OFFSET;
    
	L = 2 * (ACTUAL_R * tan((360 / $fn) / 2));
    
    ANGLE = -atan( STEP_SIZE / (L / 2) ) / 2; 
    
    OFFSET = START_R - (BOTTOM_T / 2) + SPIRAL_START_OFFSET + STEP_OFFSET;
    
    translate ([OFFSET, 0, - H / 2]) {
        rotate ([0, 0, ANGLE]) {
            //replace hull for quick render?
            //test spiral lib
            hull () {
                translate([0, 0, H]) 
                    cube([TOP_T, L, 0.1], center=true);
                    cube([BOTTOM_T, L, 0.1], center=true);   
            }
        }
    }
}

spiral(D, N);

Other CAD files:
stl/100ft_v3/gnal_100ft_spacer_16.stl
stl/50ft_v3/gnal_50ft_spacer.stl
stl/100ft_v1/gnal_100ft_top.stl
stl/100ft_v2/gnal_100ft_spacer_16.stl
scad/spiral/spiral_2.scad
scad/100ft_v1/gnal_100ft.scad
scad/100ft_v1/spacer.scad
scad/100ft_v1/spiral_bottom.scad
scad/100ft_v1/spiral_top.scad
scad/100ft_v1/top.scad
scad/100ft_v2/gnal_100ft.scad
scad/50ft_v1/gnal_50ft.scad
scad/50ft_v1/spacer.scad
scad/50ft_v1/spiral_bottom.scad
scad/50ft_v1/spiral_top.scad
scad/50ft_v1/top.scad
scad/50ft_v2/gnal_50ft.scad
scad/spiral/spiral_3.scad
scad/spiral/spiral_4.scad
scad/spiral/spiral_5.scad
scad/spiral/spiral_6.scad
scad/spiral/spiral_7.scad
stl/100ft_v1/gnal_100ft_spacer.stl
stl/100ft_v2/gnal_100ft_insert_16.stl
stl/100ft_v2/gnal_100ft_insert_s8.stl
stl/100ft_v2/gnal_100ft_spacer.stl
stl/100ft_v2/gnal_100ft_top.stl
stl/50ft_v1/gnal_50ft_spacer.stl
stl/50ft_v1/gnal_50ft_top.stl
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

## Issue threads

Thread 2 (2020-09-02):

Create a spindle for using a single spiral with the top

sixteenmillimeter, 2020-09-02:
Make a "single layer" spindle that can be used to process 16mm and Super8 on a single layer with just a spiral and a top part. This can use the existing spacers and will be something like the top of the spindle with the threading of the bottom part. Make sure that the threaded part can be re-enforced because of its likelihood of snapping from perpendicular forces.

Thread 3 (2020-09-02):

Re-enforce the outermost spiral.

sixteenmillimeter, 2020-09-02:
A section of the spiral on the 50ft reel consistently fails when printed in PETG. This has been happening across different versions. It does not occur on the example ABS and PLA prints, but it would be trivial to increase the thickness of the outer spiral for the last 1/2 turn so that it prints without "stringing" and breaking.

sixteenmillimeter, 2020-09-14:
Examining this now as a side effect of a printer defect. Using the stock tubing on the Bowden extruder for the Creality Ender 5 Plus, there were issues with layer adhesion that were not present after switching to Capricorn PTFE tubing and a new metal extruder component. This means that the model might not have to be re-enforced but further testing is needed.

sixteenmillimeter, 2021-02-18:
Does not need to be re-enforced. Was happening due to suboptimal slicer settings. Closing.

Closed 2021-02-18.

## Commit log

2020-05-21 Add gnal 50ft v1 and required dependency files
    [gnal_50ft.scad, path_extrude.scad, spacer.scad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]
2020-05-22 Rendered all 50ft V1 models to stl using v1.sh
    [gnal_50ft_spacer.stl, gnal_50ft_top.stl]
2020-05-22 Add all code for 100ft model. Rendering now.
    [gnal_100ft.scad, path_extrude.scad, spacer.scad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]
2020-05-22 Migrate libraries into ./libraries directory
    [gnal_100ft.scad, gnal_50ft.scad, path_extrude.scad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]
2020-05-22 Run benchmark script on 6 spiral approaches
    [spiral_1.scad, spiral_2.scad, spiral_3.scad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]
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2020-05-23 Files rendered with latest Openscad
    [gnal_50ft_spacer.stl, gnal_50ft_top.stl]
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2020-05-23 Publish v2. Work needs to be reconstructed and refactored from out-of-repo sources. Trying to maintain naming consistency, but work is needed to restore a complete render process for all parts
    [gnal_100ft.scad, gnal_50ft.scad]
2020-05-24 Complete and render v2. Process is running
    [gnal_100ft.scad, gnal_50ft.scad]
2020-05-25 Add insert part flags to scad files
    [gnal_100ft.scad, gnal_50ft.scad]
2020-05-25 V1 has been fully rendered, including 100ft
    [gnal_100ft_spacer.stl, gnal_100ft_top.stl, v1.csv]
2020-05-25 insert modules named correctly in gnal lib
2020-05-25 V2 build process complete and run on laptop. Rerun on desktop with later OpenSCAD. Issue: render preview fails on spirals. Could be use of --preview flag in command but I don't want to just re-render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
    [gnal_100ft_spacer.stl, gnal_100ft_top.stl, gnal_50ft_spacer.stl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]
2020-05-25 Benchmarks run. V2 script updated
    [benchmark.csv, gnal_100ft.scad, gnal_50ft.scad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]
2020-05-25 Rendered v1 and v2 images
    [gnal_100ft_spacer.stl, gnal_50ft_spacer.stl, gnal_50ft_top.stl]
2020-05-25 Render v2
    [gnal_100ft_spacer.stl, gnal_100ft_spacer_16.stl, gnal_100ft_top.stl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]
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2020-05-25 Add comments to spiral generation code (surrounding v3, which is where the most significant performance is gained). Change gnal_v2 to use library gnal_v2.scad
    [gnal_100ft.scad, gnal_50ft.scad, spiral_3.scad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]
2020-05-26 Add verbose comments, trying to figure this spiral generation out. Ahhhh!
    [spiral_3.scad, spiral_4.scad]
2020-05-26 Next-gen spiral is ready to benchmark. Generates 60 rotation spiral in 7 seconds on laptop. Wow. Hitting limits at which the spiral module overflows in the path_extrude() module. Seems to be an issue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
    [spiral_7.scad]
2020-05-26 Another spiral 2 datapoint
    [benchmark.csv]
2020-05-26 Tired of burning cpu hours on tests I know will fail, forced script to run spiral_7 tests. WOW. Also, using more recent OpenSCAD on Linux desktop I am not seeing limits on the $fn for 60 rotation spi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
    [benchmark.csv]
2020-05-26 Ran benchmark script on spiral_6 and spiral_7 on vps
    [benchmark.csv]
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2020-05-27 Update comments on spiral code
    [spiral_1.scad, spiral_7.scad]
2020-05-27 Ran benchmarking on spiral_7 on laptop just to confirm
    [benchmark.csv]
2020-05-27 Move stls from "dist" to "stl", makes more sense.
    [gnal_100ft_spacer.stl, gnal_100ft_spacer_16.stl, gnal_100ft_top.stl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]
2020-05-27 Start v3. Render time breakthrough makes it the only viable design to iterate.
    [gnal_100ft.scad, gnal_50ft.scad]
2020-05-28 V3 ready to render. TODO: fix spiral triangular voids. Need to fit inner spoke area tighter.
    [gnal_100ft.scad, gnal_50ft.scad]
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2020-05-29 Fixed spiral trianglular voids for 50ft spiral
    [gnal_50ft.scad]
2020-05-29 Allow $fn value to be passed in via argument.
    [gnal_50ft.scad]
2020-05-29 Ready to render v3
    [gnal_100ft.scad]
2020-05-29 Define $fn in argument, wasn't doing that in 100ft
    [gnal_100ft.scad, gnal_50ft.scad]
2020-05-29 Rendered all of v3
    [gnal_100ft_spacer.stl, gnal_100ft_spacer_16.stl, gnal_50ft_spacer.stl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]
2020-05-31 re-rendered v3. Images still don't work
    [gnal_100ft_spacer.stl, gnal_100ft_spacer_16.stl, gnal_50ft_spacer.stl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]
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2020-07-08 Trying spiral with thicker threads. TODO: run admesh on all stls, write out to ascii still (compare sizes to binary for distribution, though).
    [gnal_100ft_spacer.stl, gnal_100ft_spacer_16.stl, gnal_50ft.scad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]
2020-07-09 Just went for it! Added an experimental quarter version with registration notches in the quarters. Will experiment securing with locktite and determine how waterproof the joins are. Currently having 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
    TODO: quarter the 100ft spiral
    [gnal_50ft.scad]
2020-08-16 Work on quarter models
    [gnal_100ft.scad, gnal_50ft.scad]
2020-08-19 Add spindle code to v3. Render the top and bottom spindle.
    [gnal_100ft.scad, gnal_50ft.scad]
2020-08-19 Rendered spindles for the first time
    [gnal_100ft_spindle_bottom.stl, gnal_50ft_spindle_bottom.stl]
2020-08-19 Re-rendered all files and converted to binary where necessary. Logs indicate file size savings of 70-80%
    [gnal_100ft_spacer.stl, gnal_100ft_spacer_16.stl, gnal_50ft_spacer.stl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]
2020-08-19 Convert all v2 models to binary (large file size savings)
    [gnal_100ft_spacer.stl, gnal_100ft_spacer_16.stl, gnal_100ft_top.stl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]
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2020-08-19 Migrate all scad files to their own scad directory to make the root less messy. Might archive the 1-2-3 versions and properly use git for future versioning.
    [gnal_100ft.scad, gnal_50ft.scad, spacer.scad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]
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2020-08-22 Render latest updates to v3
    [gnal_100ft.scad, gnal_100ft_insert_16.stl, gnal_100ft_insert_s8.stl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]
2020-08-24 Add a "spiral test" module to render a slice of the spiral for printer tests
    [gnal_50ft.scad]
2020-08-24 Remove triangular voids from v3 and move the improved triangular voids into v2 to consolidate the best attempt at this design to that version.
    [gnal_100ft.scad, gnal_50ft.scad]
2020-08-25 Re-render v2 with better triangular voids
    [gnal_100ft.scad, gnal_100ft_insert_16.stl, gnal_100ft_insert_s8.stl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]
2020-08-29 A lot of newlines added to the readme. Sentences broken down to 1 line each instead of 1 line per paragraph. This will better track changes over time with smaller diffs per sentence.
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2020-09-12 Simplify v3 scripts by removing vestigial modules.
    [gnal_100ft.scad, gnal_50ft.scad]
2021-02-18 Render the new single-layer spindle. Still needs to be rendered and added to the README.
    [gnal_100ft.scad, gnal_50ft.scad]
2021-02-18 Add engraved roman numerals into the spindle screws to tell the difference between the double layer and the single layer spindles.
    [gnal_100ft.scad]
2021-02-18 Change default model to "spiral"
    [gnal_100ft.scad]
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2026-02-01 Prototype of the top spindle with hole for an m4 hex bolt to reinforce it's strength is done, not ready for merge. Will have to evaluate all progress done on stacking.
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2026-04-19 Add reinforced spindles. Refactore build process to use new manifold backend correctly on new builds of OpenSCAD. Add releases to repo to fix download links. Add CSG build but not ready for STEP conv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
    [gnal_100ft.scad, gnal_100ft_insert_16.stl, gnal_100ft_insert_s8.stl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]
2026-04-19 Run the manifold backend tests
    [manifold.csv]
